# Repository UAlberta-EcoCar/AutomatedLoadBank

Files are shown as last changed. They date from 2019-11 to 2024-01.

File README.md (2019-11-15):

# AutomatedLoadBank
Python user interface for Raspberry Pi driven automated load bank

### Project Abstract
An automated resistive load bank was created to test and optimize hydrogen fuel cells for the University of Alberta EcoCar team. The load bank utilizes a touchscreen graphical user interface to select automated testing cycles and pulse width modulation for a variable load. The load bank handles up to 60 A of current from the 46 V fuel cell with 1000 W of power dissipation capability. Furthermore, it is battery powered, portable, and weather resistant.

### Software Overview
The automated load bank is managed primarily by a Raspberry Pi computer, and its I/O capabilities are extended using an Atmel ATMega328P. In this repository lies the software for the Raspberry Pi. The software is primarily written in Python and uses the TkInter graphics library to develop a touchscreen user interface.

### Communication With Other Modules
#### ATMega328P via I2C
*Raspberry Pi to ATMega328P*
* 0 -- Stop output
* 1-120 -- Desired load in steps. Step size is 0.5 A, so a value of 64 would correspond to a 32 A load.
* 121 -- Start an air starve cycle. Operating parameters are set in the ATMega328P.
* 122 -- Data request for all inputs read by ATMega328P. (Fuel cell voltage, fuel cell current, battery voltage)
* 123 -- Trigger to tell ATMega328P that fan speeds will be sent next.
* **WARNING:** Sending values greater than 123 will be interpreted by the ATMega328P as desired current values of greater than 60 A which is outside the design parameters for the hardware.

*ATMega328P to Raspberry Pi*

### Version History

### Pi Configurations Necessary to Run this Software
**Install Raspbian operating system using Etcher to put the latest image on an SD card**\
    [TUTORIAL](https://www.raspberrypi.org/documentation/installation/installing-images/)
    
**Set date for Wi-Fi access**\
  `sudo date -s "Dec 27 14:54"`
    
**Update software repositories & installed software**\
  [TUTORIAL](https://www.raspberrypi.org/documentation/raspbian/updating.md)\
  `sudo apt-get update`\
  `sudo apt-get dist-upgrade`

**Install "Matchbox" on-screen software keyboard**\
  `sudo apt-get install matchbox-keyboard`
    
**Install TkInter and Python image library**\
`sudo apt-get install tk`\
`sudo apt-get install python-imaging`\
`sudo apt-get install python-imaging-tk`\
`sudo apt-get install python3-pil.imagetk`

**Set Python3 as default environment**\
Edit bash file: `nano ~/.bashrc`\
Add at the end:
```
alias python='/usr/bin/python3'
alias pip=pip3
```
Run bash file: `source ~/.bashrc`

**Enable I2C**\
`sudo raspi-config` -> **5 Interfacing Options** -> **P5 I2C** -> **yes** -> **Finish**

**Set I2C Speed**\
[REFERENCE](https://www.raspberrypi-spy.co.uk/2018/02/change-raspberry-pi-i2c-bus-speed/)\
`sudo nano /boot/config.txt`\
`dtparam=i2c_arm=on,i2c_arm_baudrate=15000` (for 15kHz baud rate)

**Add Matplotlib dependencies**
```
sudo apt-get install libatlas3-base libffi-dev at-spi2-core python3-gi-cairo
pip install cairocffi
pip install matplotlib
```

### Handy Features/Resources
**Display brightness**\
`sudo bash -c "echo n > /sys/class/backlight/rpi_backlight/brightness"`\
where 0 < n < 255 (255 is maximum brightness)\
[*Alternate Method*](https://raspberrypi.stackexchange.com/questions/46225/adjusting-the-brightness-of-the-official-touchscreen-display)
```
>>> import rpi_backlight as bl
>>> bl.set_brightness(255)
>>> bl.set_brightness(20, smooth=True, duration=3)
>>> bl.get_max_brightness()
255
>>> bl.get_actual_brightness()
20
>>> bl.get_power()
True
>>> bl.set_power(False)
```

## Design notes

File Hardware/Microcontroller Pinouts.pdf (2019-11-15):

## Raspberry Pi

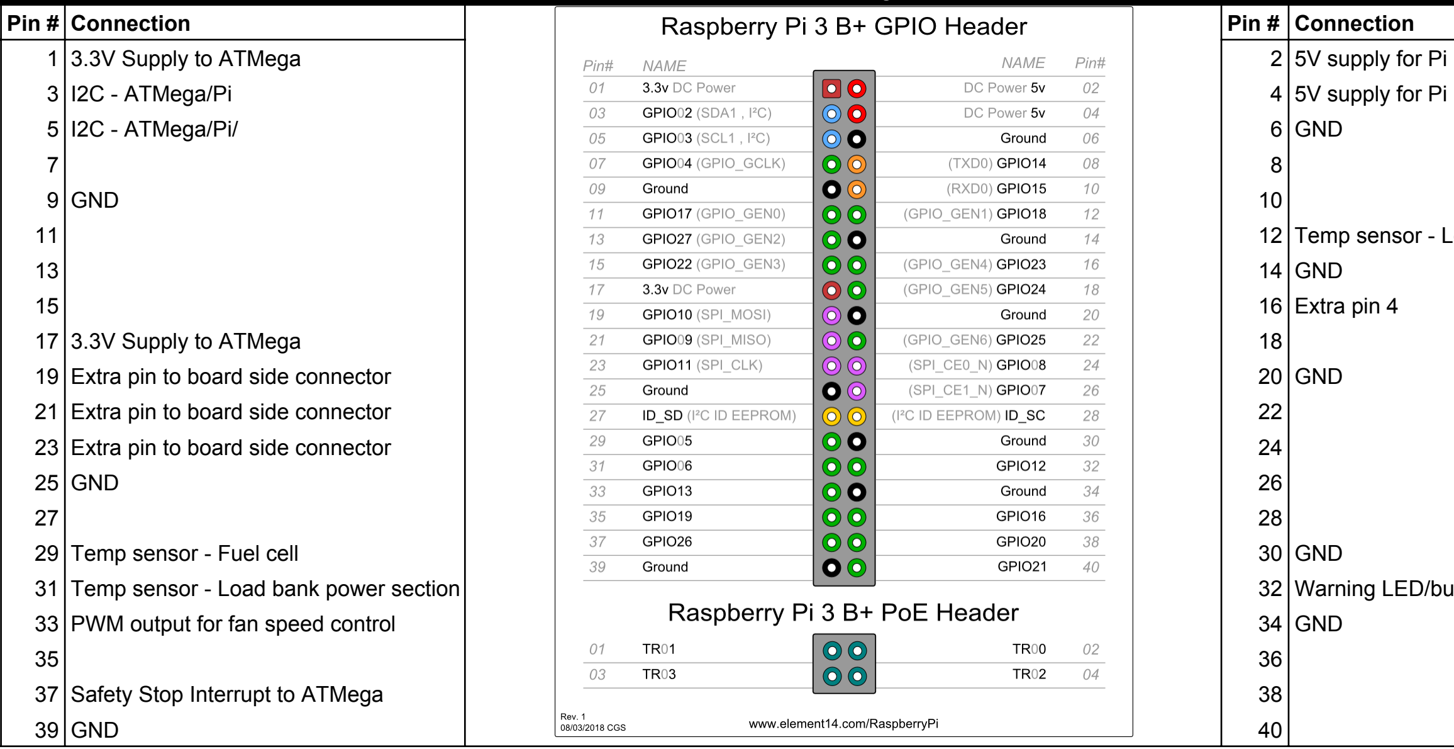
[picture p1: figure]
Pin #; Connection; 3.3V Supply to ATMega; 5V supply for Pi; I2C - ATMega/Pi; I2C - ATMega/Pi/; GND; Extra pin 4; Extra pin to board side connector; Temp sensor - Fuel cell; Safety Stop Interrupt to ATMega

11 | 12 | Temp sensor - Load bank electronics
19 | Extra pin to board side connector | 20 | GND
31 | Temp sensor - Load bank power section | 32 | Warning LED/buzzer output
33 | PWM output for fan speed control | 34 | GND

## Atmel ATMega 328P

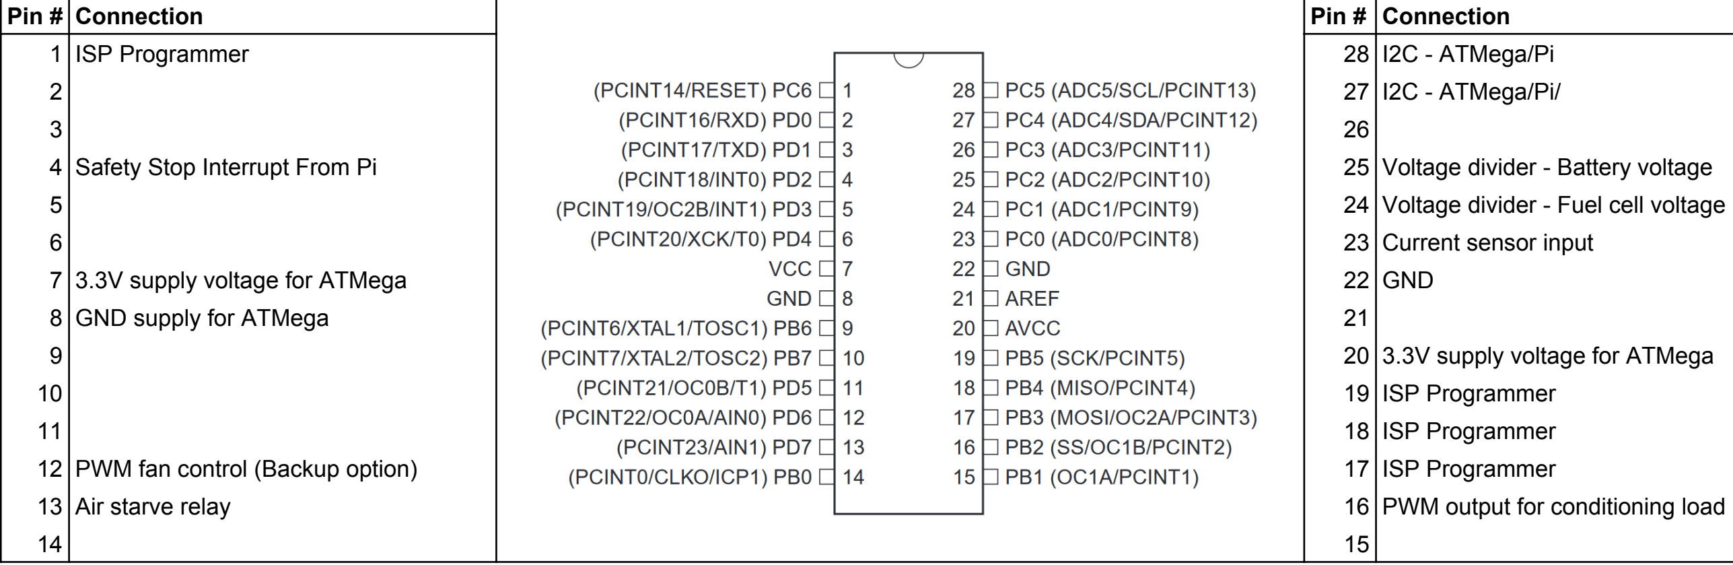
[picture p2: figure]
Pin #; Connection; ISP Programmer; I2C - ATMega/Pi; I2C - ATMega/Pi/; Safety Stop Interrupt From Pi; Voltage divider - Battery voltage; Current sensor input; 3.3V supply voltage for ATMega; GND; GND supply for ATMega; PWM fan control (Backup option); Air starve relay; PWM output for conditioning load

5 | 24 | Voltage divider - Fuel cell voltage

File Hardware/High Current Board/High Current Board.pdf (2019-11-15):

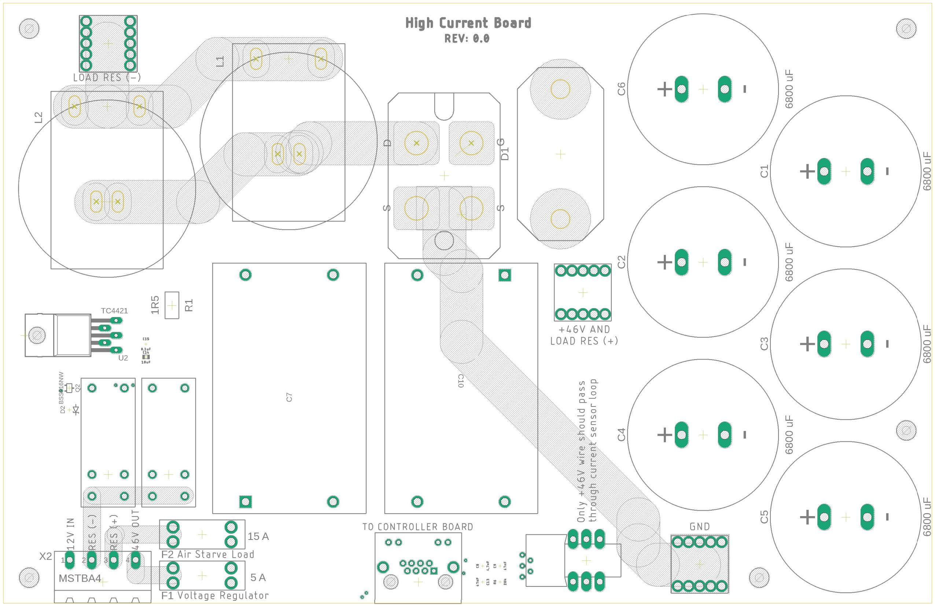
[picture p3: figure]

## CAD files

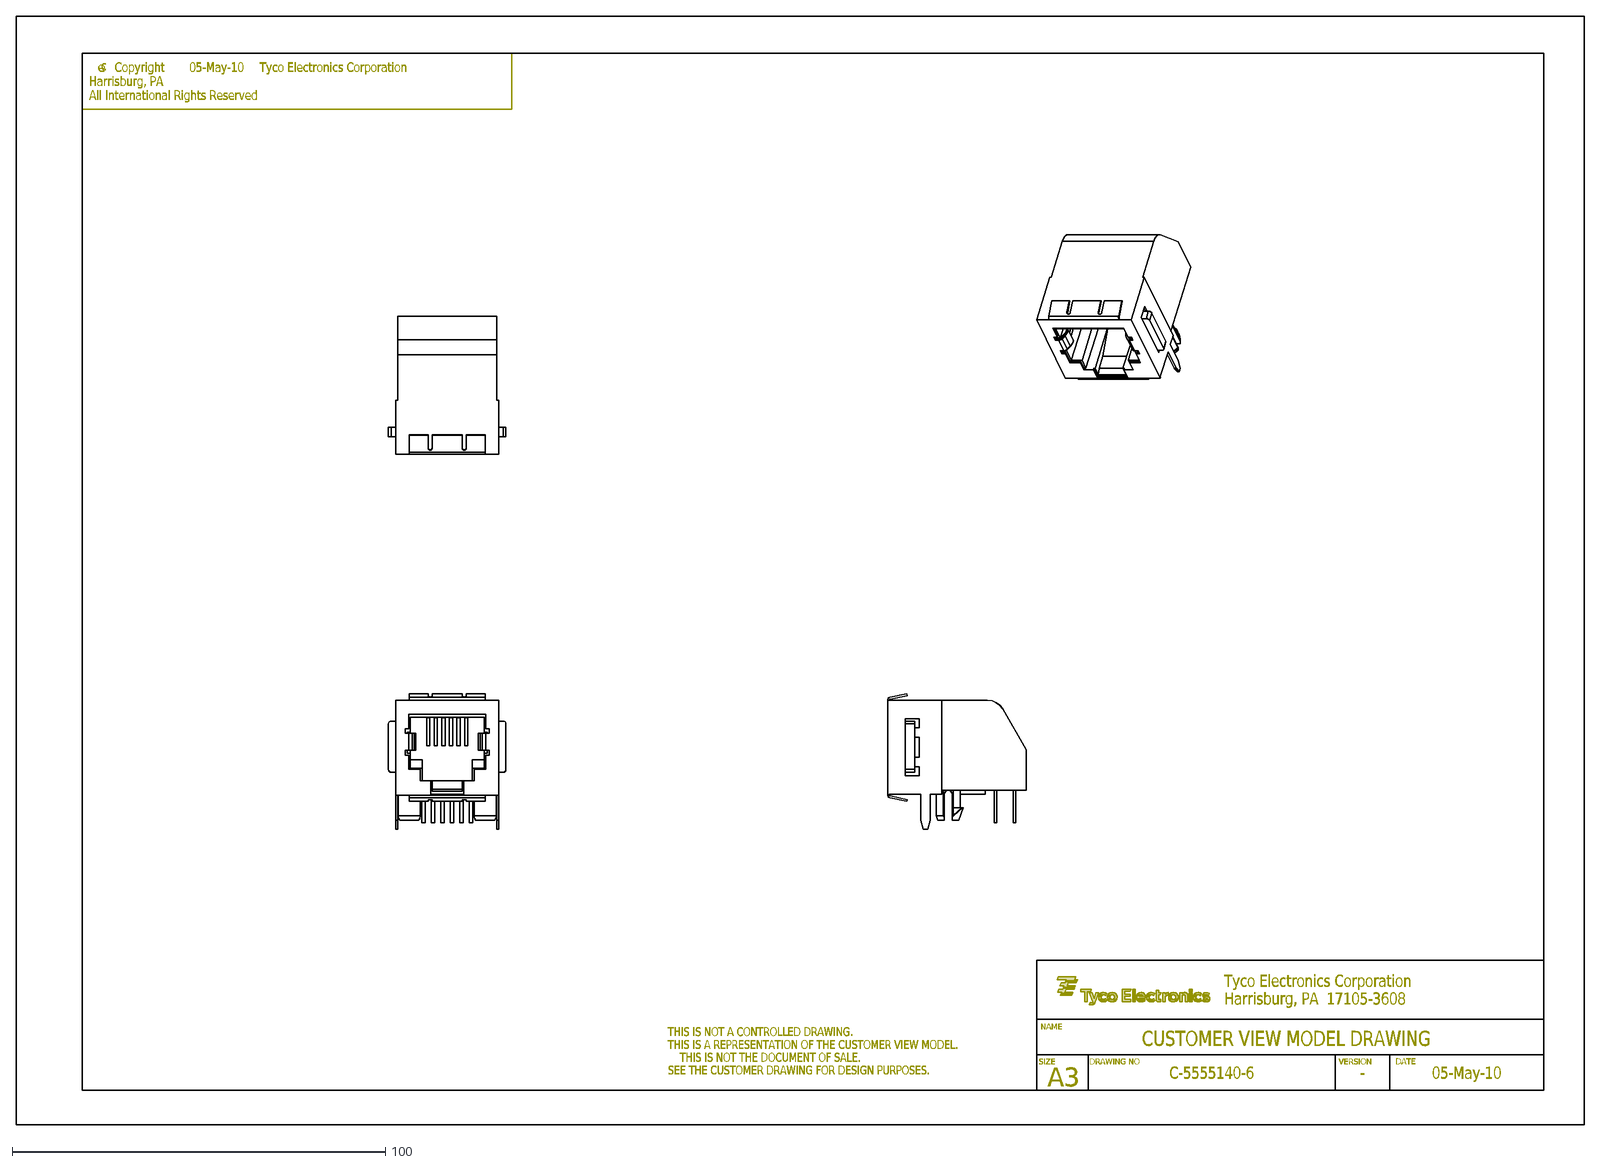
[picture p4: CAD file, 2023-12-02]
references/c-5555140-6-e-2d.dxf
SIZE
DRAWING NO
VERSION
NAME
A3
CUSTOMER VIEW MODEL DRAWING
Tyco Electronics Corporation
Harrisburg, PA 17105-3608
DATE
THIS IS NOT A CONTROLLED DRAWING.
THIS IS A REPRESENTATION OF THE CUSTOMER VIEW MODEL.
THIS IS NOT THE DOCUMENT OF SALE.
SEE THE CUSTOMER DRAWING FOR DESIGN PURPOSES.
c
C-5555140-6
-
05-May-10
Copyright
Harrisburg, PA
All International Rights Reserved

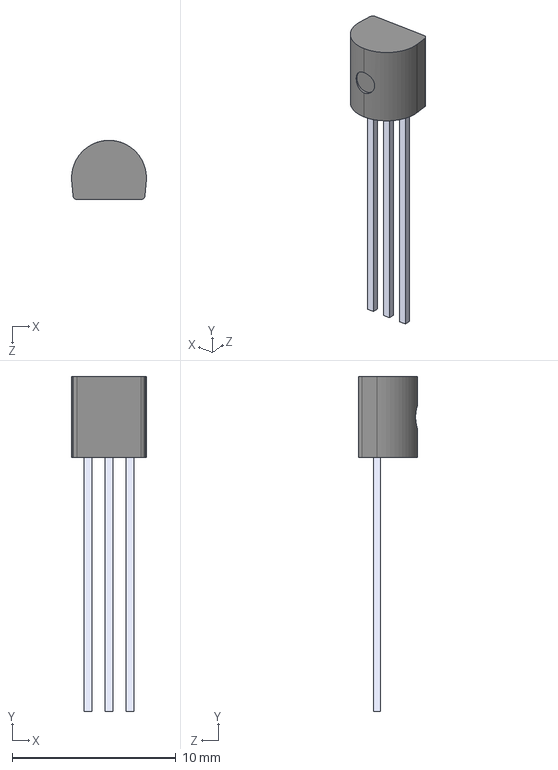
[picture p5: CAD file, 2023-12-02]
references/DS18B20/DS18B20.step
4.57 x 20.4 x 3.62 mm

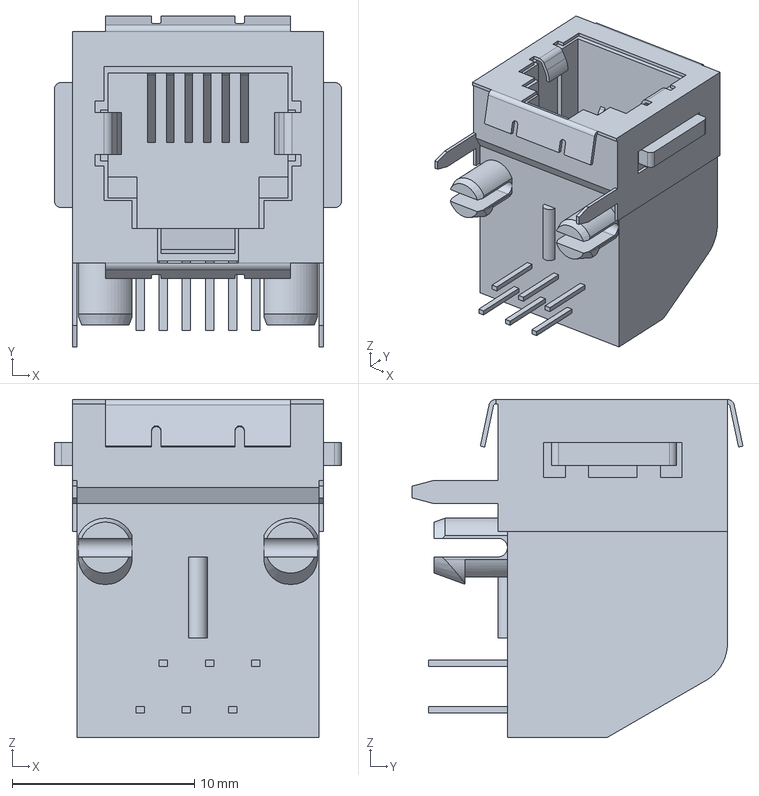
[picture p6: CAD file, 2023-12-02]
references/c-5555140-6-e-3d.stp
15.7 x 18.1 x 18.5 mm

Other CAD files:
references/c-5555140-6-e-3d.igs

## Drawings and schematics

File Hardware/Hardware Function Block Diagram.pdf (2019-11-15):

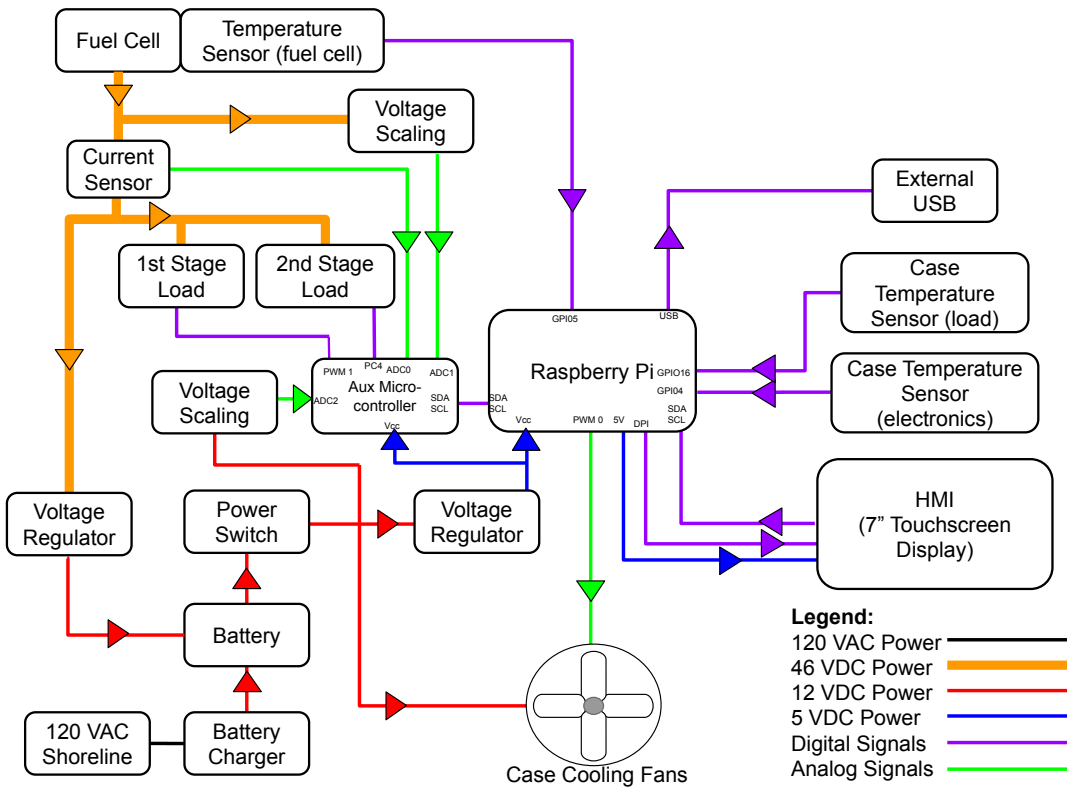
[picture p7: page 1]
Legend: 120 VAC Power 46 VDC Power 12 VDC Power 5 VDC Power Digital Signals Analog Signals; Fuel Cell; 120 VAC Shoreline; Raspberry Pi; HMI (7” Touchscreen Display); Case Temperature Sensor (load); Case Temperature Sensor (electronics); External USB; Battery; Voltage Regulator; Power Switch; Voltage Scaling; Battery Charger; 1st Stage Load; 2nd Stage Load; Current Sensor; Aux Micro- controller ADC2; PWM 1; ADC0; ADC1; SDA SCL; SDA SCL Vcc Vcc; GPI05; GPI04; GPIO16; USB; PWM 0; DPI; SDA; SCL

Temperature
Sensor (fuel cell)

Case Cooling Fans

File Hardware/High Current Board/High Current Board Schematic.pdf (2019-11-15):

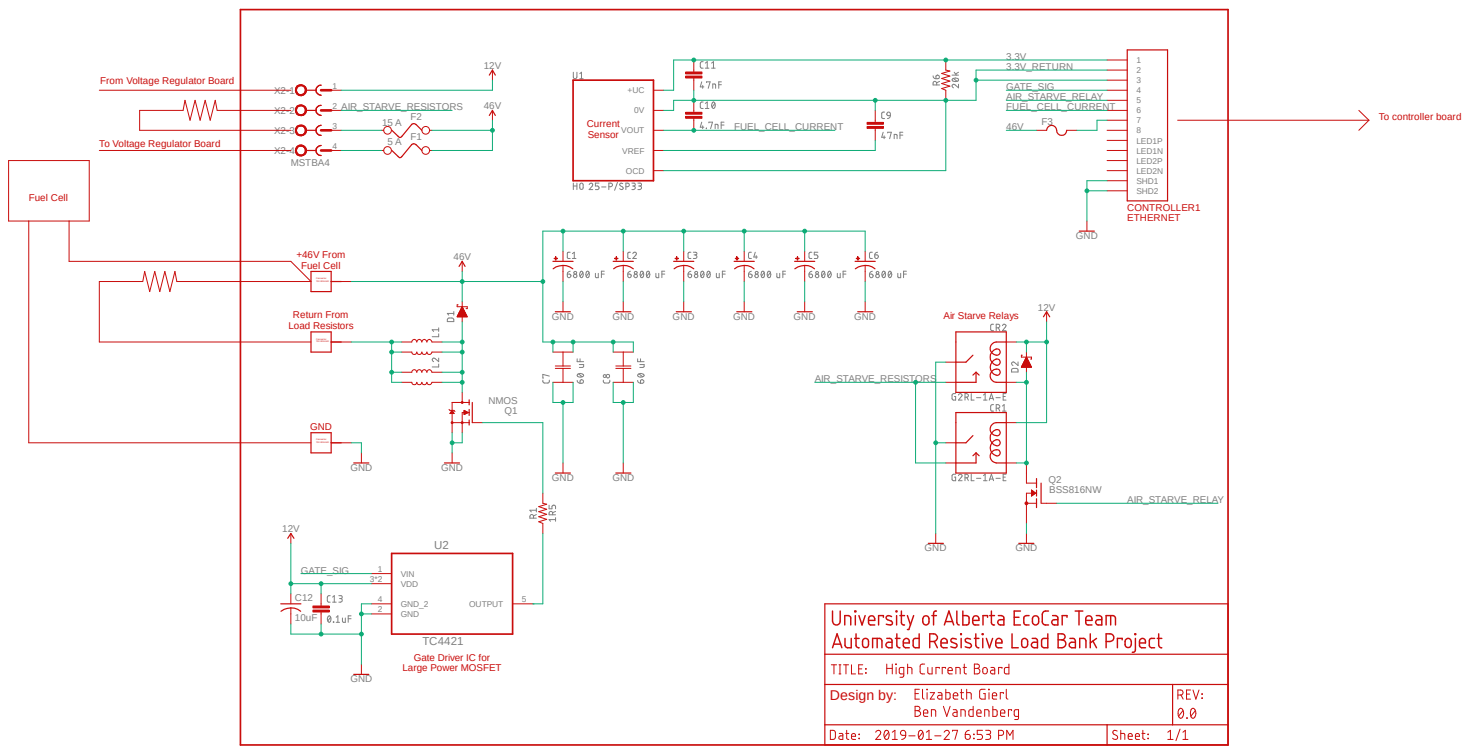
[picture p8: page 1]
GND; 46V GND; NMOS GND; BSS816NW; MSTBA4; GND GND; 1 2 3 4 5 6 7 8 LED1P LED1N LED2P LED2N SHD1 SHD2 Q2; GND 2; GND_2 4; OUTPUT; 5 VDD 3*2; VIN 1; F3 FUEL_CELL_CURRENT; FUEL_CELL_CURRENT; 3.3V 3.3V_RETURN; AIR_STARVE_RELAY; GATE_SIG; AIR_STARVE_RESISTORS; Current Sensor +46V From; Fuel Cell; To controller board To Voltage Regulator Board; From Voltage Regulator Board; Connector 732-3204-ND Connector 732-3204-ND; Design by:; Connector 732-3204-ND; CONTROLLER1 ETHERNET

VOUT VREF OCD Q1

Fuel Cell Return From

Air Starve Relays Gate Driver IC for Large Power MOSFET

Load Resistors GND

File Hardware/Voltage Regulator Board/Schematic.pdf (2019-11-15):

## INGND

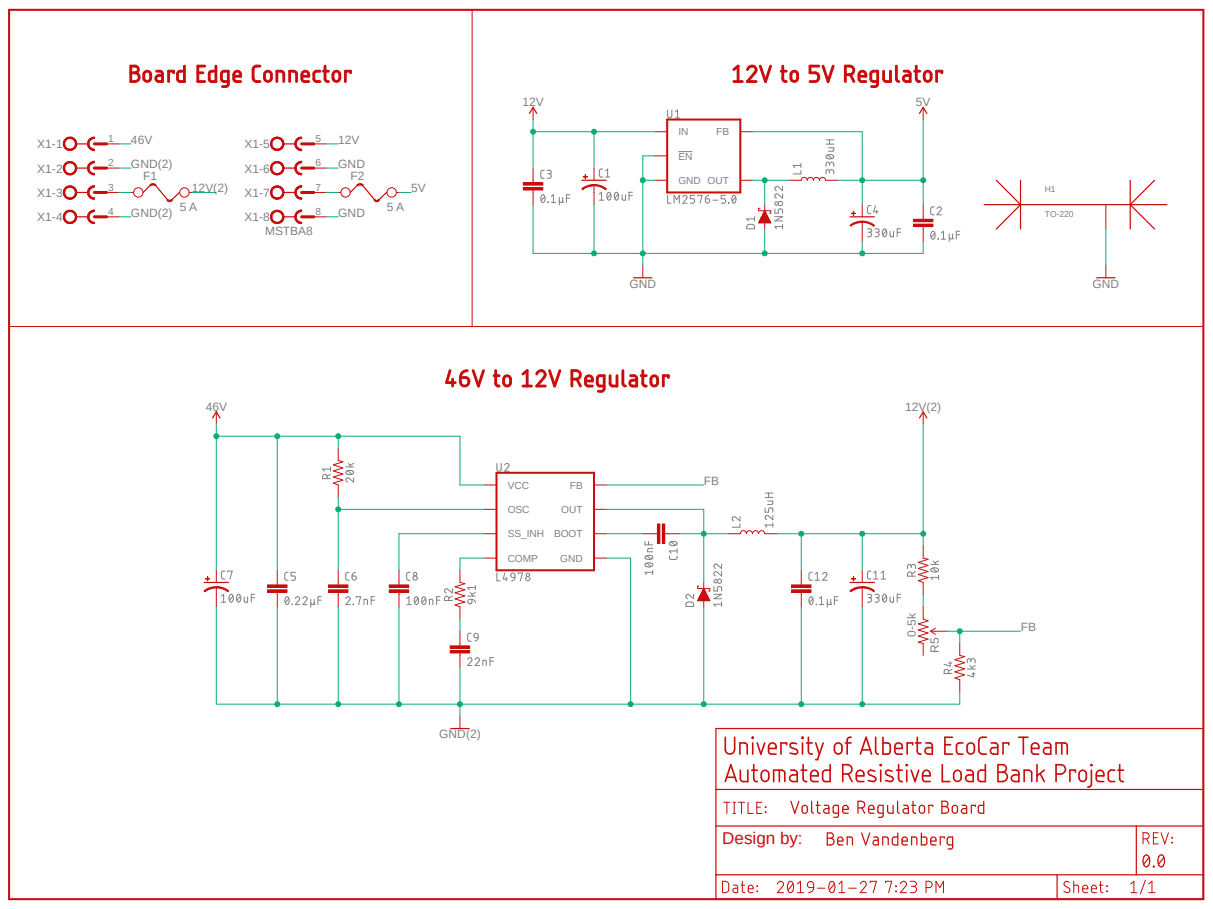
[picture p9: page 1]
GND; GND(2); MSTBA8; OUT; VCC; SS_INH; FB OSC; BOOT OUT COMP; Design by:

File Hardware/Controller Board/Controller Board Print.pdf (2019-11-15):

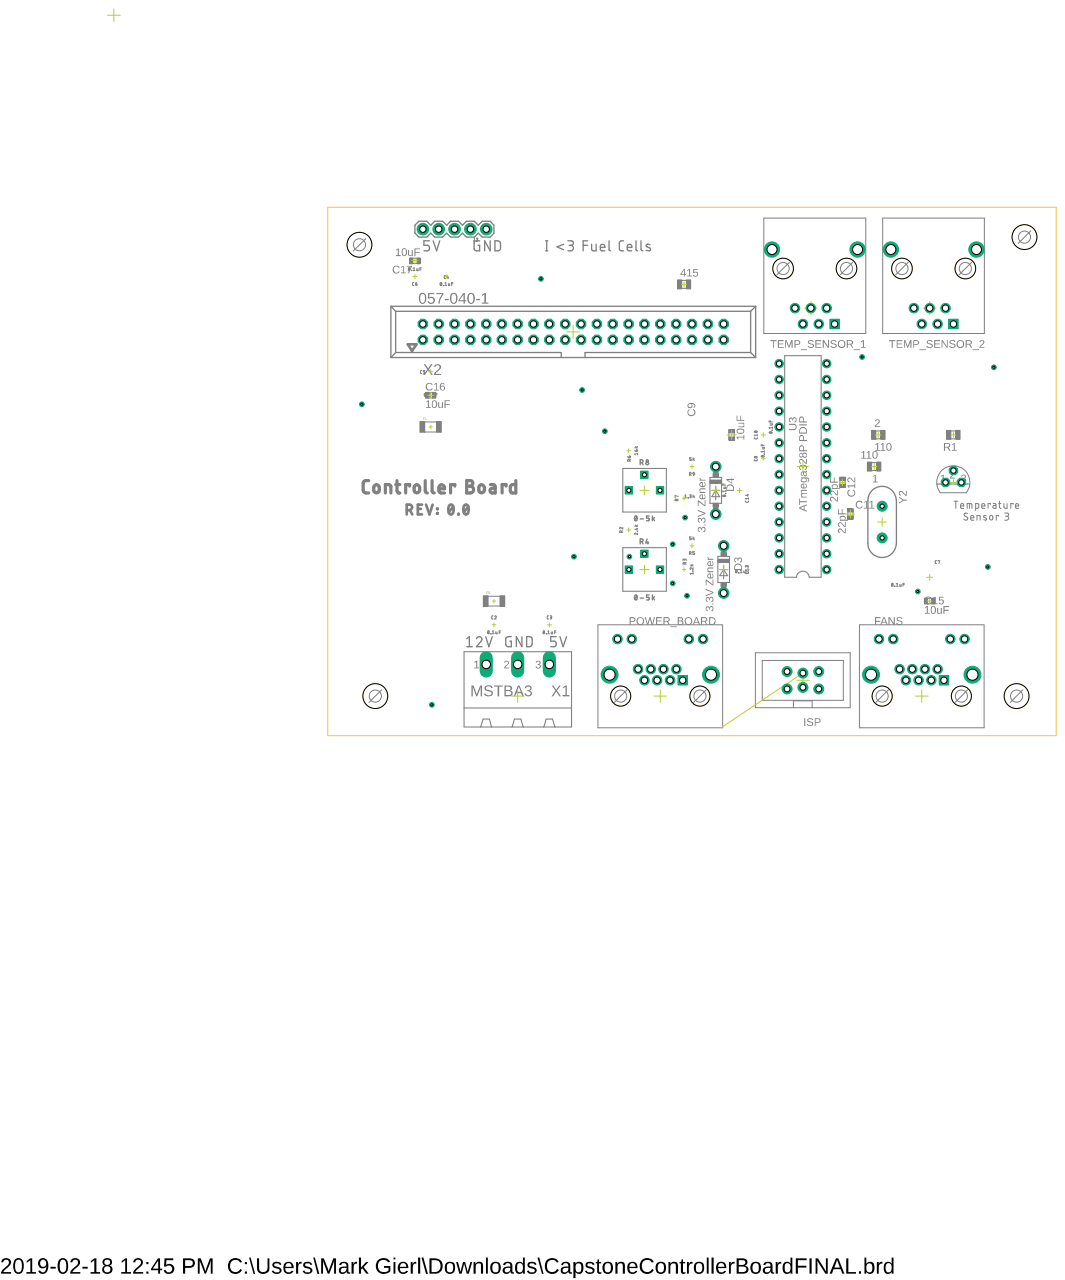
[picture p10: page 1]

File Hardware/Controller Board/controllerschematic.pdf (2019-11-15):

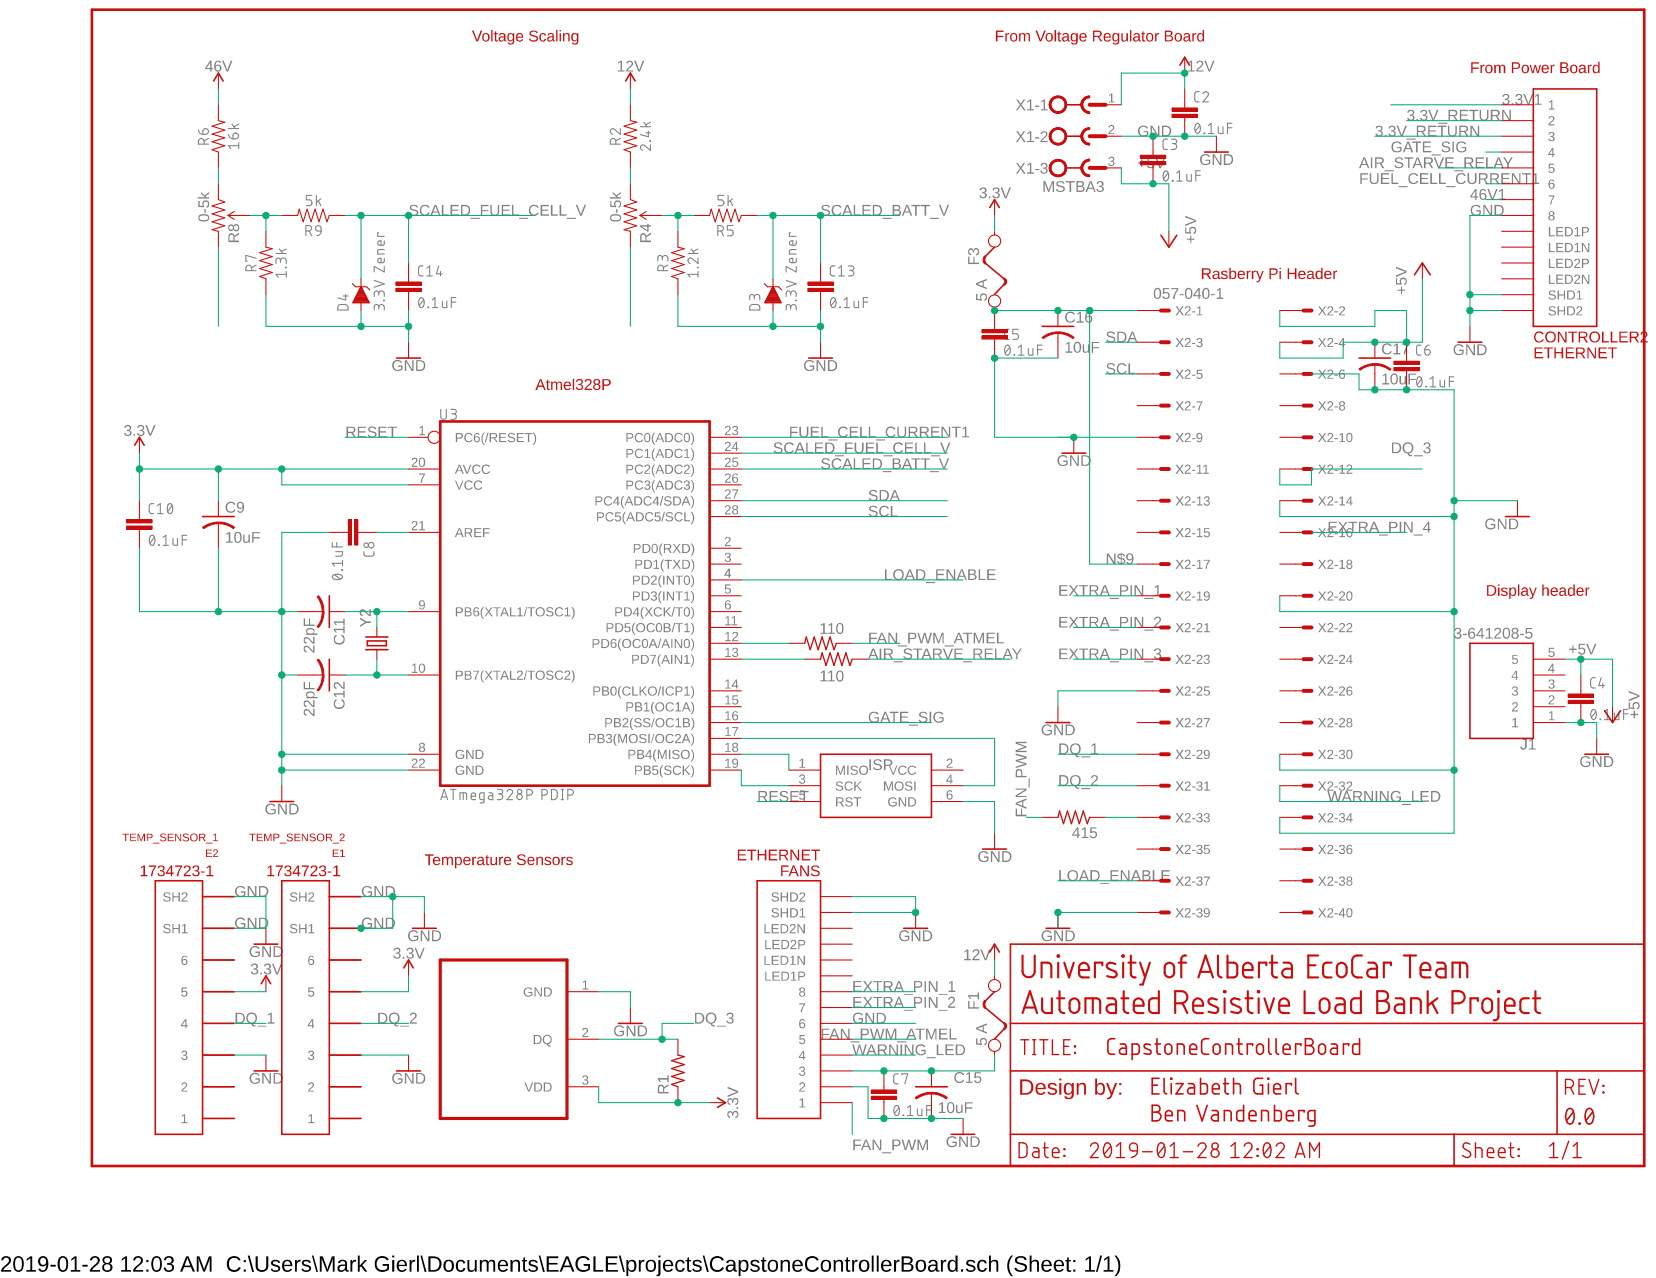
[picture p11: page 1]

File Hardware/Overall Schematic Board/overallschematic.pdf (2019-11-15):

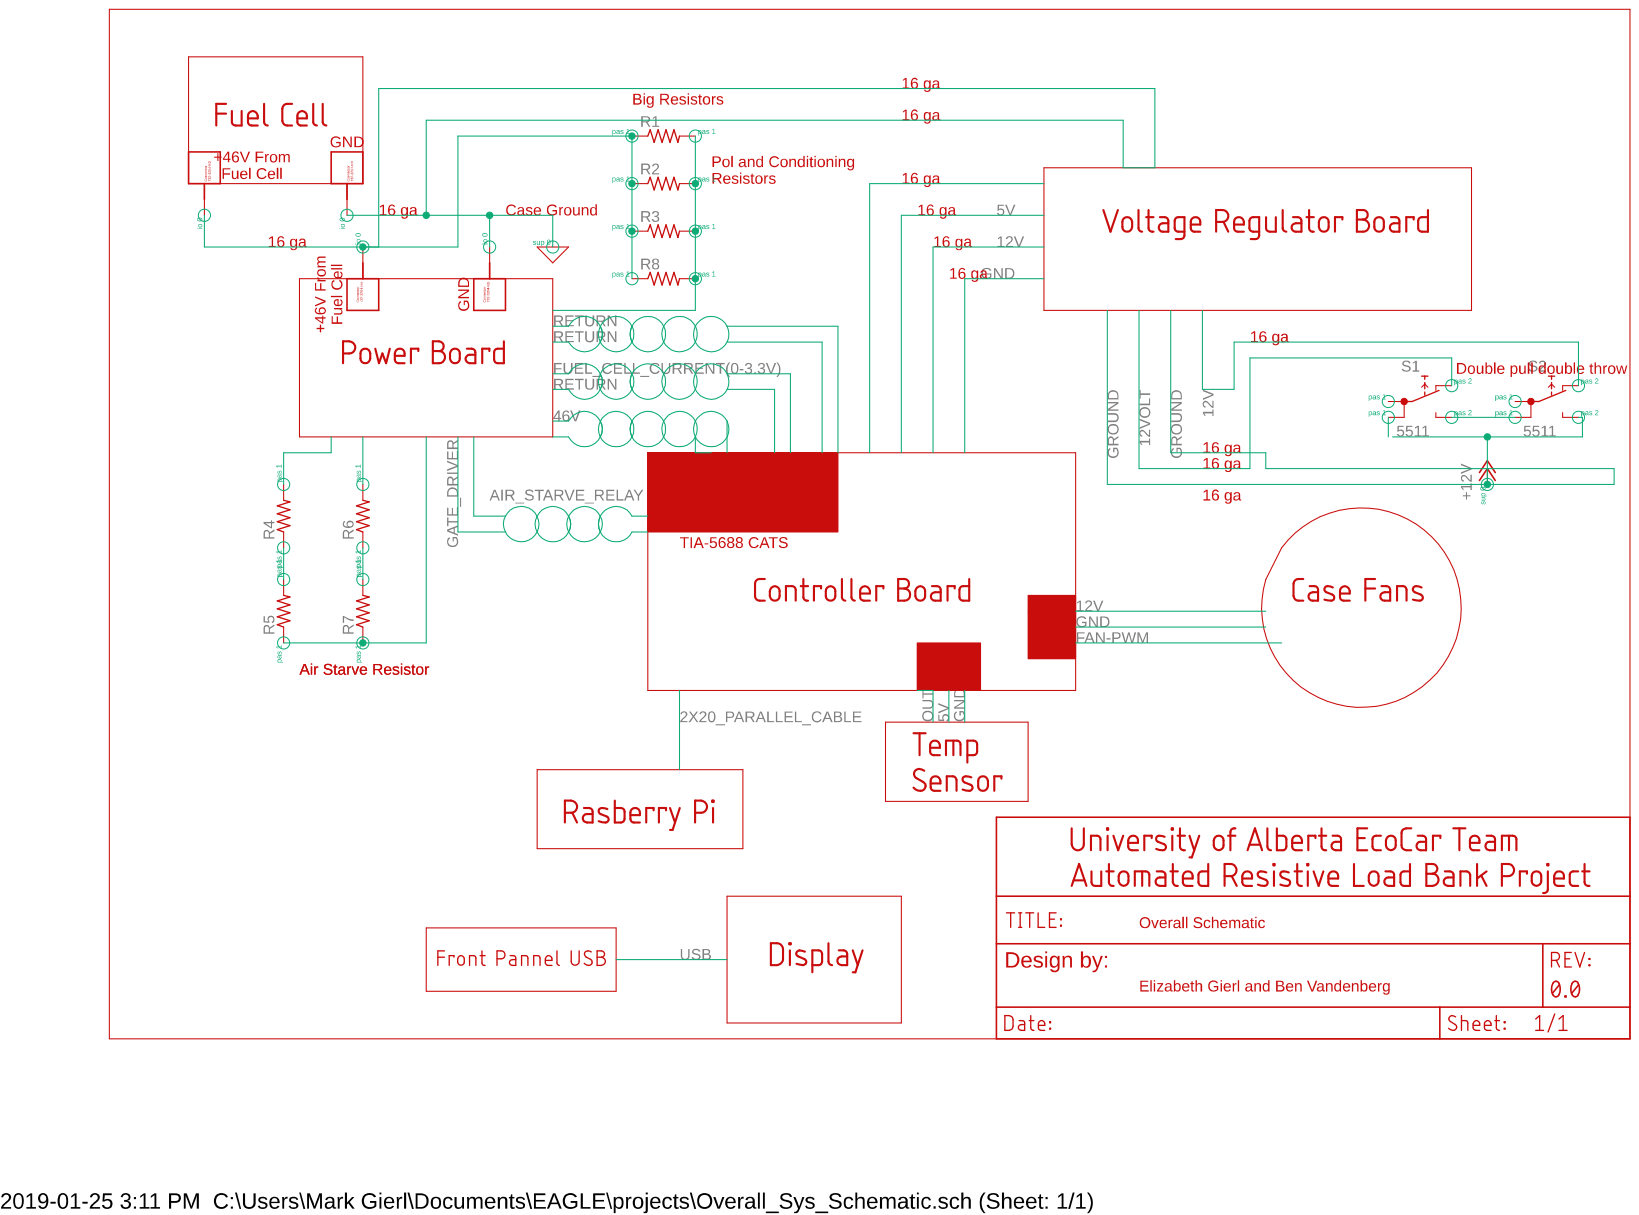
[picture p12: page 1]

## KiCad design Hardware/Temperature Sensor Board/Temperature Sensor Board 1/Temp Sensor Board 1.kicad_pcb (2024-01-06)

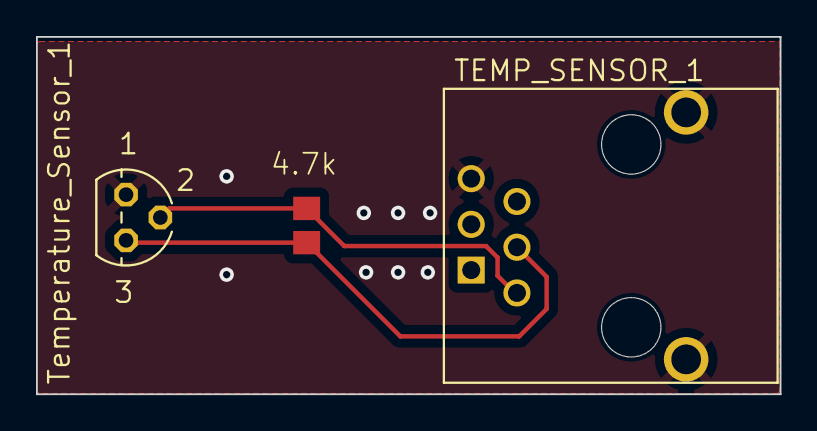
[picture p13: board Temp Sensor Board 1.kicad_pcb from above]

Board: 2 copper layers, 41.3 x 19.9 mm, 3 parts (0 on the bottom side), 3 nets.

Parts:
4.7k: R; R0805
J1: 6P6C; 1734723-1_RJ11
U$1: Temperature_Sensor_1; TO92-3

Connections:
/DQ: 4.7k.1, J1.4, U$1.2 (DQ)
/GND: J1.3, J1.SH1, J1.SH2, U$1.1 (GND)
/VDD: 4.7k.2, J1.5, U$1.3 (VDD)

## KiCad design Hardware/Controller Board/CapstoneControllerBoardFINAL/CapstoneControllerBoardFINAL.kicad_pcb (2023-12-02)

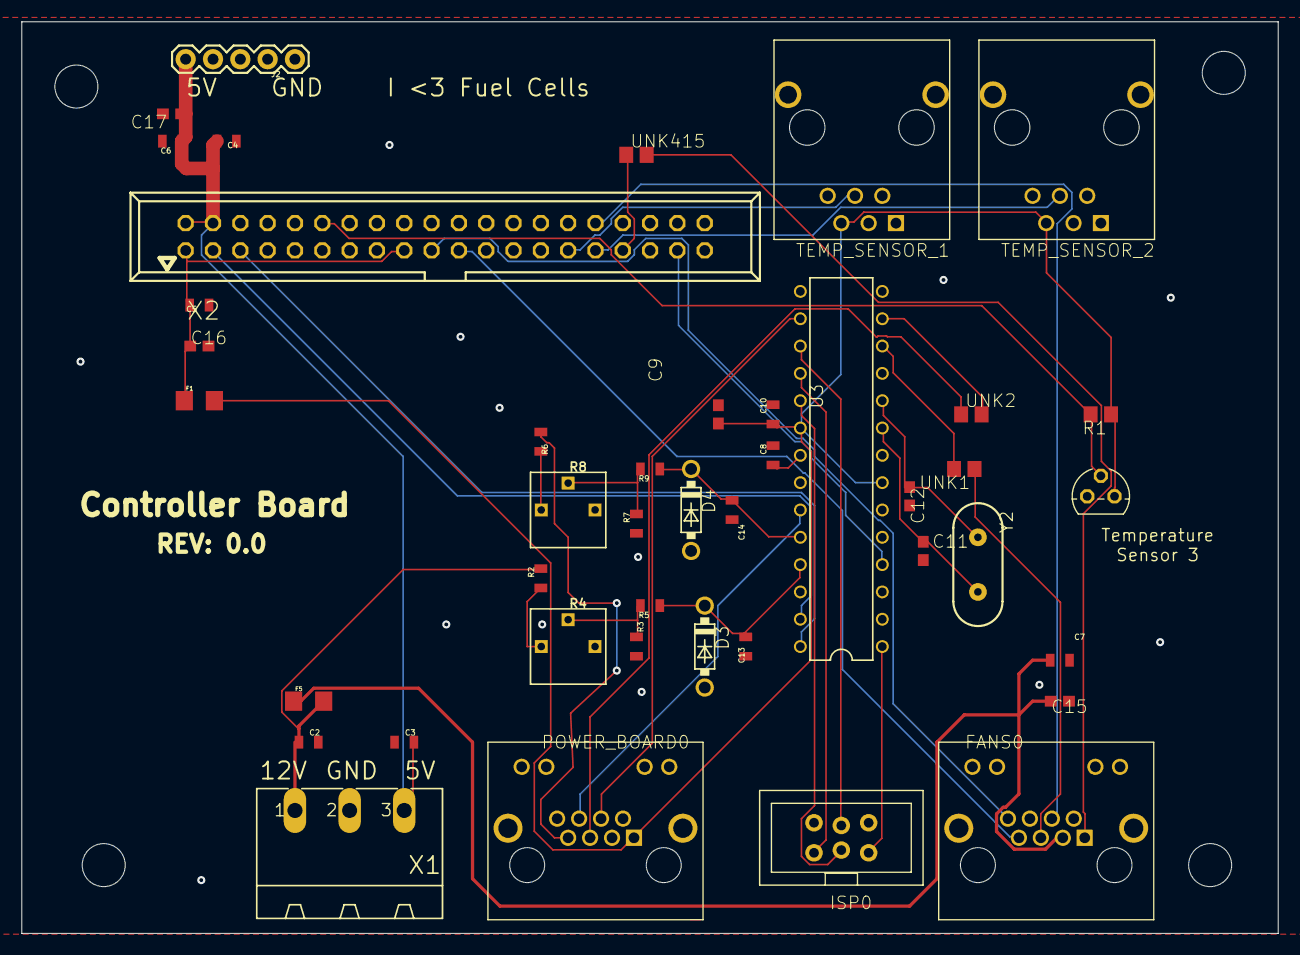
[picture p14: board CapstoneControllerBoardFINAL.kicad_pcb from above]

Board: 2 copper layers, 116.8 x 84.8 mm, 48 parts (0 on the bottom side), 37 nets.

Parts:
@HOLE0, @HOLE1, @HOLE2, @HOLE3: (no value)
C2, C3, C4, C5, C6, C7, C8, C10, C13, C14: 0.1uF; 0805
C9, C15, C16, C17: 10uF; C0603
C11, C12: 22pF; C0603
D3, D4: 3.3V Zener; DO41-7.6
F1, F5: 1206
FANS0: ETHERNET; A122645-ND
FRAME2: FRAME-LETTERNO_PACKAGE; DUMMY
ISP0: AVRISP-BOX
J2: 1X05
POWER_BOARD0: ETHERNET; A122645-ND
R1: R0805
R2: 2.4k; 0805
R3: 1.2k; 0805
R4, R8: 0-5k; TRIM_POT
R5, R9: 5k; 0805
R6: 16k; 0805
R7: 1.3k; 0805
TEMP_SENSOR_1, TEMP_SENSOR_2: 5555140-6; 1734723-1_RJ11
U3: ATmega328P PDIP; PDIP-T28
U$2: DS18B; TO92
UNK1, UNK2: 110; R0805
UNK415: R0805
X1: MSTBA3
X2: 057-040-1
Y2: HC49US

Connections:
3.3V: C9.1, C10.1, F1.2, POWER_BOARD0.P$1, R1.1, TEMP_SENSOR_1.5, TEMP_SENSOR_2.5, U3.7, U3.20, U$2.3
12V: C2.1, F5.2, R2.2, X1.1
46V: POWER_BOARD0.P$7, R6.2
+5V: C3.2, C4.1, C6.1, C17.1, J2.5, X1.3, X2.2, X2.4
AIR_STARVE_RELAY: POWER_BOARD0.P$5, UNK2.1
DQ_1: TEMP_SENSOR_1.4, X2.29
DQ_2: TEMP_SENSOR_2.4, X2.31
DQ_3: R1.2, U$2.2, X2.12
EXTRA_PIN_1: FANS0.P$8, X2.19
EXTRA_PIN_2: FANS0.P$7, X2.21
FAN_PWM: FANS0.P$1, UNK415.2
FAN_PWM_ATMEL: FANS0.P$5, UNK1.1
FUEL_CELL_CURRENT1: POWER_BOARD0.P$6, U3.23
GATE_SIG: POWER_BOARD0.P$4, U3.16
GND: C2.2, C3.1, C4.2, C5.2, C6.2, C7.2, C8.2, C9.2, C10.2, C11.2, C12.2, C13.2, C14.2, C15.2, C16.2, C17.2, D3.A, D4.A, FANS0.P$2, FANS0.P$6, FANS0.P$13, FANS0.P$14, ISP0.6, J2.1, POWER_BOARD0.P$2, POWER_BOARD0.P$3, POWER_BOARD0.P$8, POWER_BOARD0.P$13, POWER_BOARD0.P$14, R3.1, R7.1, TEMP_SENSOR_1.3, TEMP_SENSOR_1.SH1, TEMP_SENSOR_1.SH2, TEMP_SENSOR_2.3, TEMP_SENSOR_2.SH1, TEMP_SENSOR_2.SH2, U3.8, U3.22, U$2.1, X1.2, X2.9, X2.14, X2.20, X2.25, X2.30, X2.39
LOAD_ENABLE: U3.4, X2.37
unnamed: C8.1, U3.21
unnamed: ISP0.1, U3.18
unnamed: ISP0.3, U3.19
unnamed: UNK415.1, X2.33
unnamed: R2.1, R4.1
unnamed: U3.12, UNK1.2
unnamed: C5.1, C16.1, F1.1, X2.1, X2.17
unnamed: R6.1, R8.1
unnamed: R3.2, R4.2, R5.2
unnamed: ISP0.4, U3.17
unnamed: C11.1, U3.9, Y2.2
unnamed: C12.1, U3.10, Y2.1
unnamed: R7.2, R8.2, R9.2
unnamed: C7.1, C15.1, F5.1, FANS0.P$3
unnamed: U3.13, UNK2.2
RESET: ISP0.5, U3.1
SCALED_BATT_V: C13.1, D3.C, R5.1, U3.25
SCALED_FUEL_CELL_V: C14.1, D4.C, R9.1, U3.24
SCL: U3.28, X2.5
SDA: U3.27, X2.3
WARNING_LED: FANS0.P$4, X2.32

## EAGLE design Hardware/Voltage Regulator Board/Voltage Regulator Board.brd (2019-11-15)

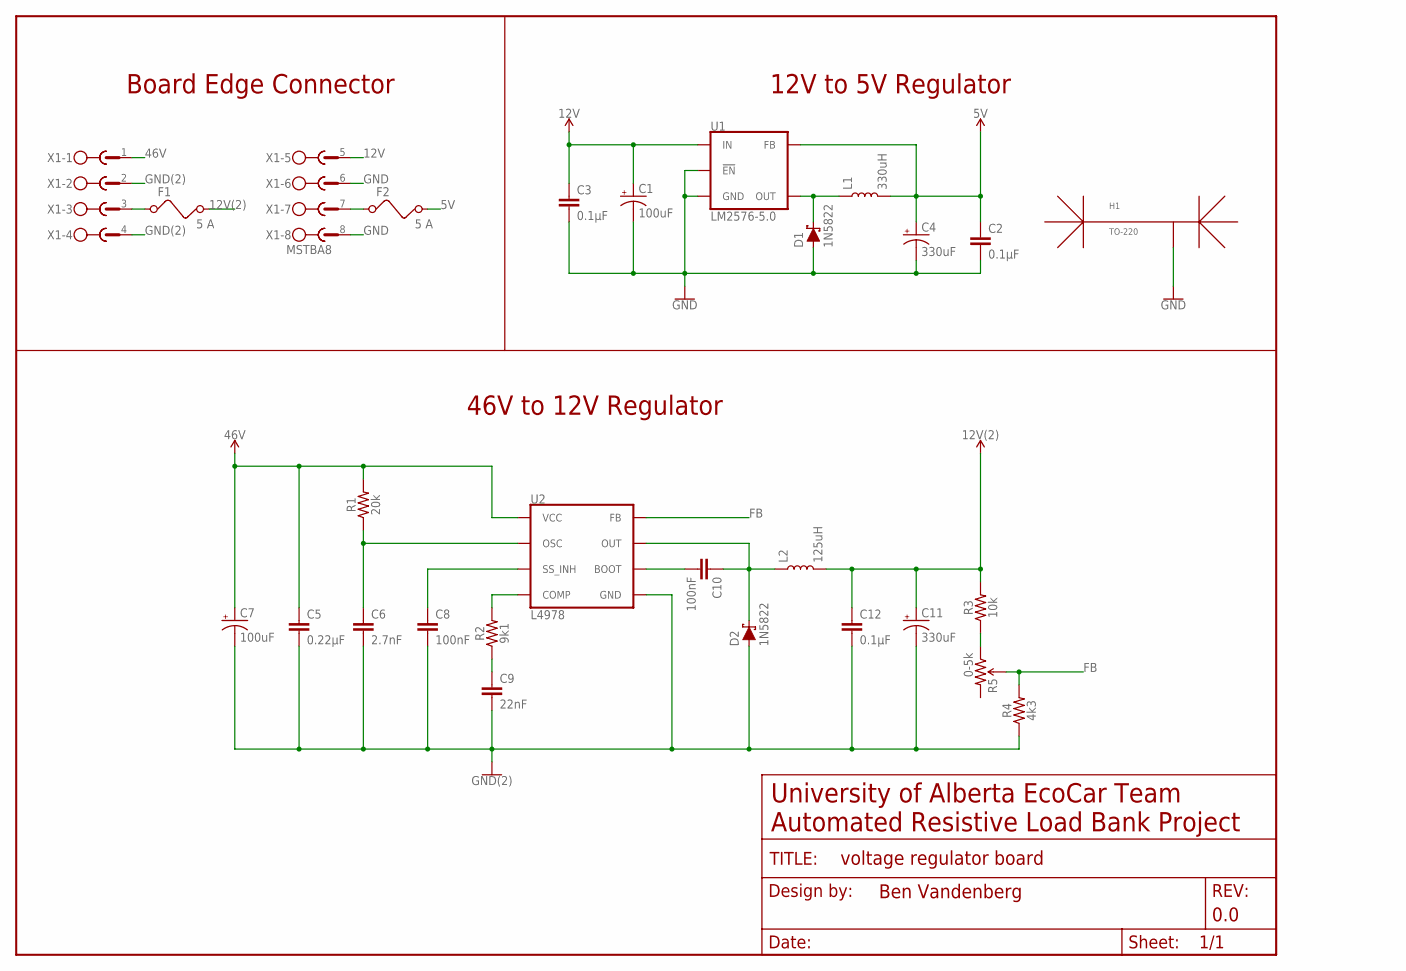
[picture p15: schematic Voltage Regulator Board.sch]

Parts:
C1, C7: 100uF; CPOL-RADIAL-3.5MM-8MM
C2, C3, C12: 0.1µF; 0805
C4, C11: 330uF; CPOL-RADIAL-5MM-10MM
C5: 0.22µF; 0805
C6: 2.7nF; 0805
C8, C10: 100nF; 0805
C9: 22nF; 0805
D1, D2: 1N5822; DO201T15
F1, F2: 5 A; KEYSTONE_ATM_FUSEHOLDER
FRAME1: FRAME-LETTERNO_PACKAGE; DUMMY
H1: TO-220; HSE-B250-04H_HEATSINK
L1: 330uH; 330UH_PTH_INDUCTOR
L2: 125uH; 125UH_PTH_INDUCTOR
R1: 20k; 0805
R2: 9k1; 0805
R3: 10k; 0805
R4: 4k3; 0805
R5: 0-5k; TRIM_POT
U1: LM2576-5.0; TO220-5
U2: L4978; DIP08
X1: MSTBA8

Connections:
5V: C2.1, C4.+, F2.R1 (2), F2.R2 (2), L1.P$2 (2), U1.4 (FB)
12V: C1.+, C3.1, U1.1 (IN), X1.5
12V(2): C11.+, C12.1, F1.R1 (2), F1.R2 (2), L2.P$2 (2), R3.2
46V: C5.1, C7.+, R1.2, U2.5 (VCC), X1.1
FB: R4.2, R5.2 (WIPER), U2.8 (FB)
GND: C1.-, C2.2, C3.2, C4.-, D1.A, H1.GND@1, H1.GND@2, U1.3 (GND), U1.5 (!EN), X1.6, X1.8
GND(2): C5.2, C6.2, C7.-, C8.2, C9.2, C11.-, C12.2, D2.A, R4.1, U2.1 (GND), X1.2, X1.4
unnamed: F1.L1 (1), F1.L2 (1), X1.3
unnamed: C6.1, R1.1, U2.3 (OSC)
unnamed: C8.1, U2.2 (SS_INH)
unnamed: R2.2, U2.7 (COMP)
unnamed: C9.1, R2.1
unnamed: F2.L1 (1), F2.L2 (1), X1.7
unnamed: C10.2, U2.6 (BOOT)
unnamed: C10.1, D2.C, L2.P$1 (1), U2.4 (OUT)
unnamed: R3.1, R5.1 (CCW)
OUT: D1.C, L1.P$1 (1), U1.2 (OUT)

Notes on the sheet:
University of Alberta EcoCar Team Automated Resistive Load Bank Project
12V to 5V Regulator
46V to 12V Regulator
Board Edge Connector

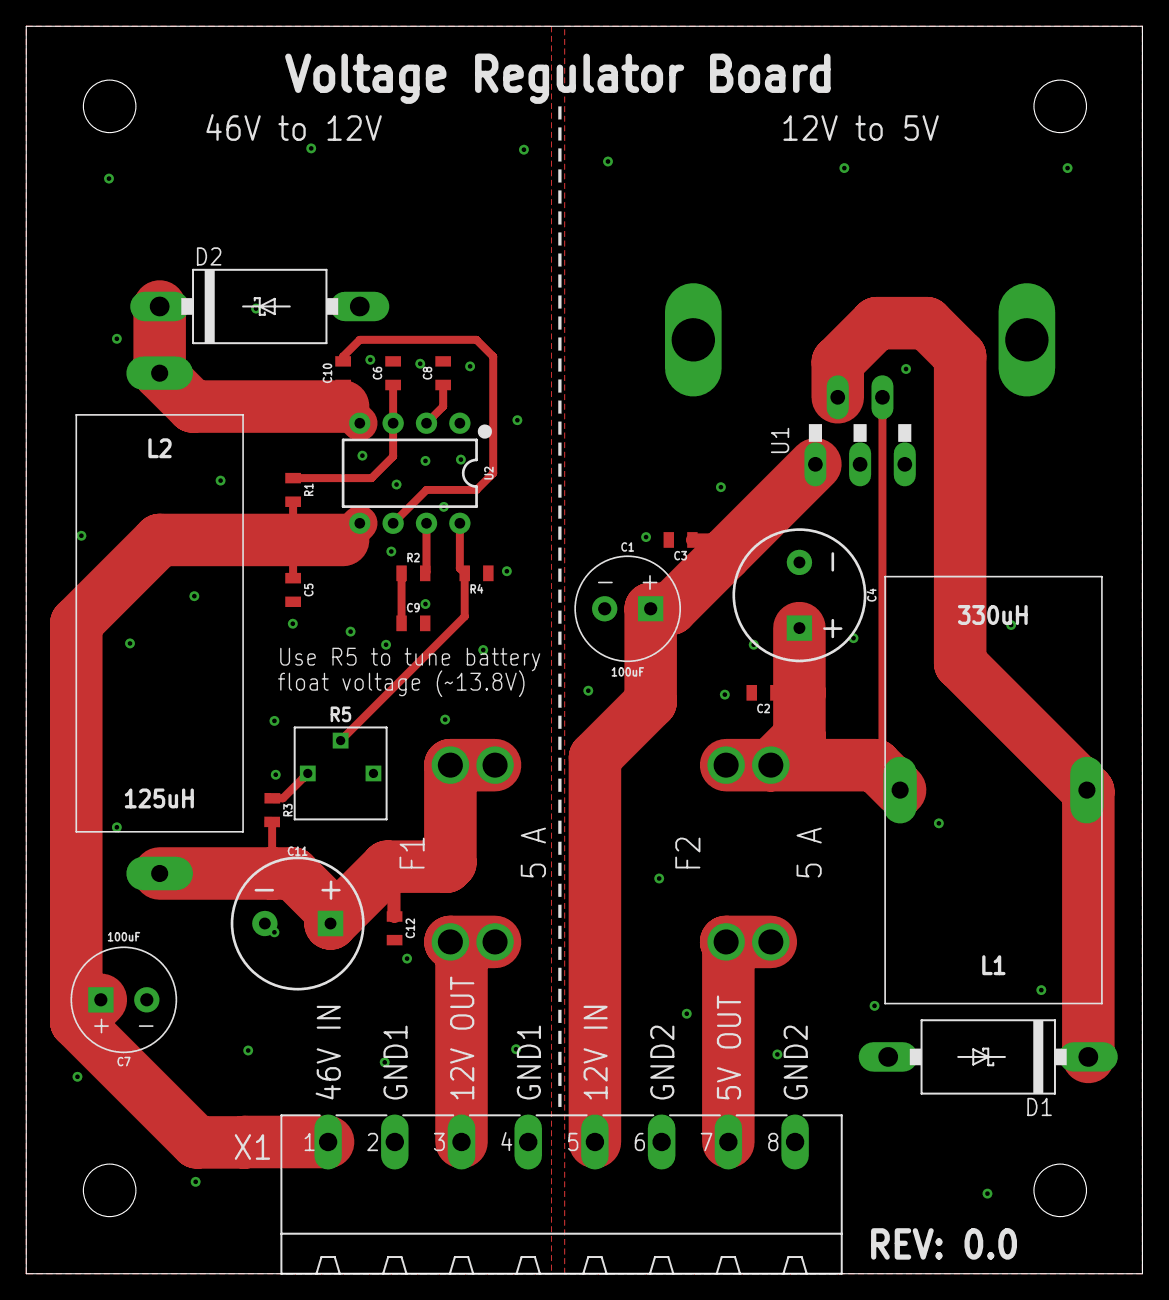
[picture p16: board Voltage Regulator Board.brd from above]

Board: 2 copper layers, 85.0 x 95.0 mm, 28 parts (0 on the bottom side), 17 nets.

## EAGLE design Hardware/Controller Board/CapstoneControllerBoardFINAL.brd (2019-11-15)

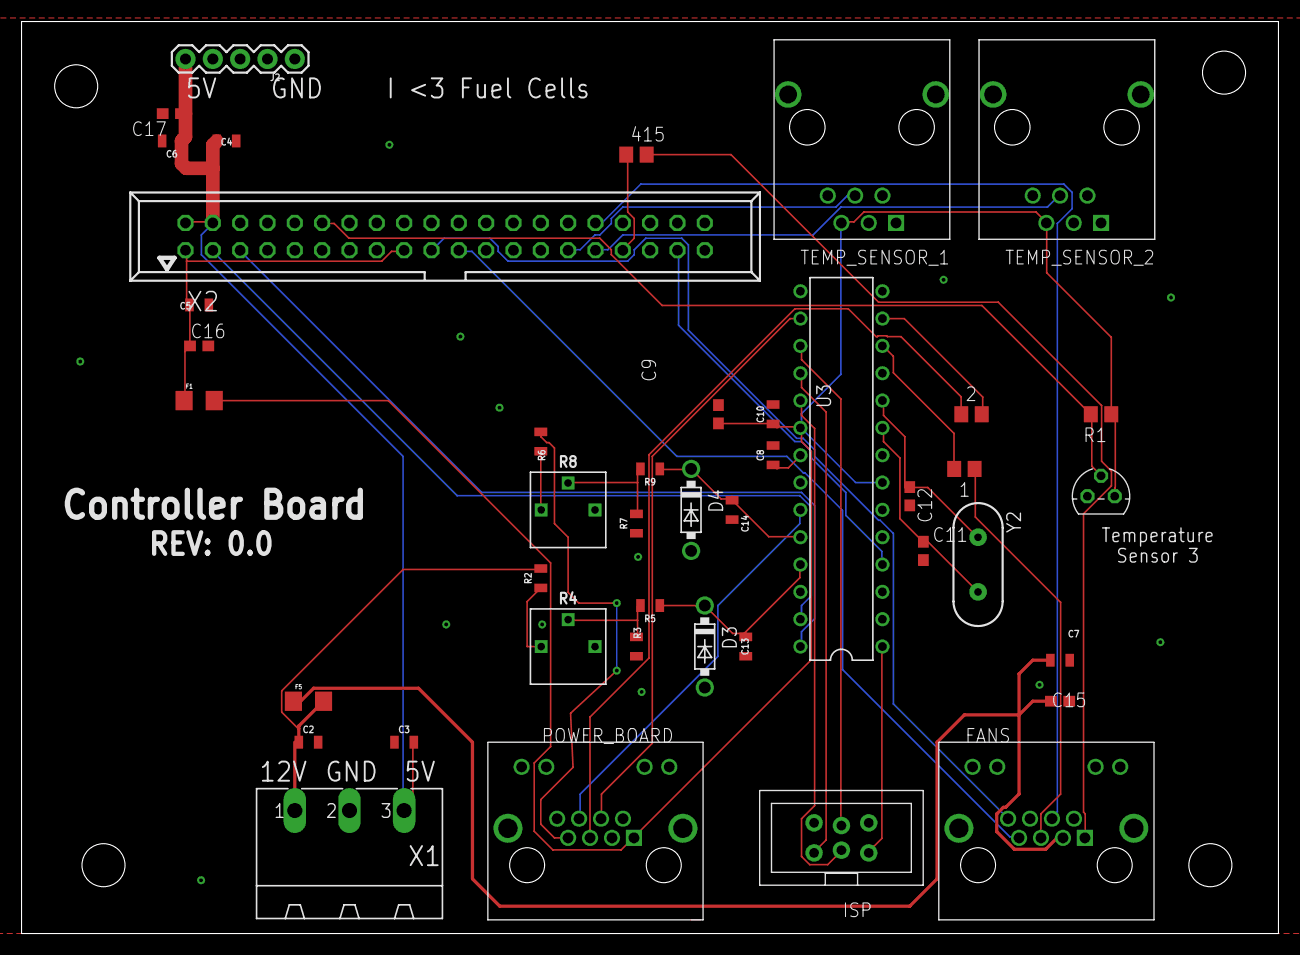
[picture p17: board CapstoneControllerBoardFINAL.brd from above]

Board: 2 copper layers, 116.8 x 84.8 mm, 44 parts (0 on the bottom side), 37 nets.

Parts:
1, 2: 110; R0805
415: R0805
C2, C3, C4, C5, C6, C7, C8, C10, C13, C14: 0.1uF; 0805
C9, C15, C16, C17: 10uF; C0603
C11, C12: 22pF; C0603
D3, D4: 3.3V Zener; DO41-7.6
F1, F5: 1206
FANS: ETHERNET; A122645-ND
FRAME2: FRAME-LETTERNO_PACKAGE; DUMMY
ISP: AVRISP-BOX
J2: 1X05
POWER_BOARD: ETHERNET; A122645-ND
R1: R0805
R2: 2.4k; 0805
R3: 1.2k; 0805
R4, R8: 0-5k; TRIM_POT
R5, R9: 5k; 0805
R6: 16k; 0805
R7: 1.3k; 0805
TEMP_SENSOR_1, TEMP_SENSOR_2: 5555140-6; 1734723-1_RJ11
U3: ATmega328P PDIP; PDIP-T28
U$2: DS18B; TO92
X1: MSTBA3
X2: 057-040-1
Y2: HC49US

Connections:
3.3V: C9.1, C10.1, F1.2, POWER_BOARD.P$1, R1.1, TEMP_SENSOR_1.5, TEMP_SENSOR_2.5, U3.7, U3.20, U$2.3
12V: C2.1, F5.2, R2.2, X1.1
46V: POWER_BOARD.P$7, R6.2
+5V: C3.2, C4.1, C6.1, C17.1, J2.5, X1.3, X2.2, X2.4
AIR_STARVE_RELAY: 2.1, POWER_BOARD.P$5
DQ_1: TEMP_SENSOR_1.4, X2.29
DQ_2: TEMP_SENSOR_2.4, X2.31
DQ_3: R1.2, U$2.2, X2.12
EXTRA_PIN_1: FANS.P$8, X2.19
EXTRA_PIN_2: FANS.P$7, X2.21
FAN_PWM: 415.2, FANS.P$1
FAN_PWM_ATMEL: 1.1, FANS.P$5
FUEL_CELL_CURRENT1: POWER_BOARD.P$6, U3.23
GATE_SIG: POWER_BOARD.P$4, U3.16
GND: C2.2, C3.1, C4.2, C5.2, C6.2, C7.2, C8.2, C9.2, C10.2, C11.2, C12.2, C13.2, C14.2, C15.2, C16.2, C17.2, D3.A, D4.A, FANS.P$2, FANS.P$6, FANS.P$13, FANS.P$14, ISP.6, J2.1, POWER_BOARD.P$2, POWER_BOARD.P$3, POWER_BOARD.P$8, POWER_BOARD.P$13, POWER_BOARD.P$14, R3.1, R7.1, TEMP_SENSOR_1.3, TEMP_SENSOR_1.SH1, TEMP_SENSOR_1.SH2, TEMP_SENSOR_2.3, TEMP_SENSOR_2.SH1, TEMP_SENSOR_2.SH2, U3.8, U3.22, U$2.1, X1.2, X2.9, X2.14, X2.20, X2.25, X2.30, X2.39
LOAD_ENABLE: U3.4, X2.37
unnamed: C8.1, U3.21
unnamed: ISP.1, U3.18
unnamed: ISP.3, U3.19
unnamed: 415.1, X2.33
unnamed: R2.1, R4.1
unnamed: 1.2, U3.12
unnamed: C5.1, C16.1, F1.1, X2.1, X2.17
unnamed: R6.1, R8.1
unnamed: R3.2, R4.2, R5.2
unnamed: ISP.4, U3.17
unnamed: C11.1, U3.9, Y2.2
unnamed: C12.1, U3.10, Y2.1
unnamed: R7.2, R8.2, R9.2
unnamed: C7.1, C15.1, F5.1, FANS.P$3
unnamed: 2.2, U3.13
RESET: ISP.5, U3.1
SCALED_BATT_V: C13.1, D3.C, R5.1, U3.25
SCALED_FUEL_CELL_V: C14.1, D4.C, R9.1, U3.24
SCL: U3.28, X2.5
SDA: U3.27, X2.3
WARNING_LED: FANS.P$4, X2.32

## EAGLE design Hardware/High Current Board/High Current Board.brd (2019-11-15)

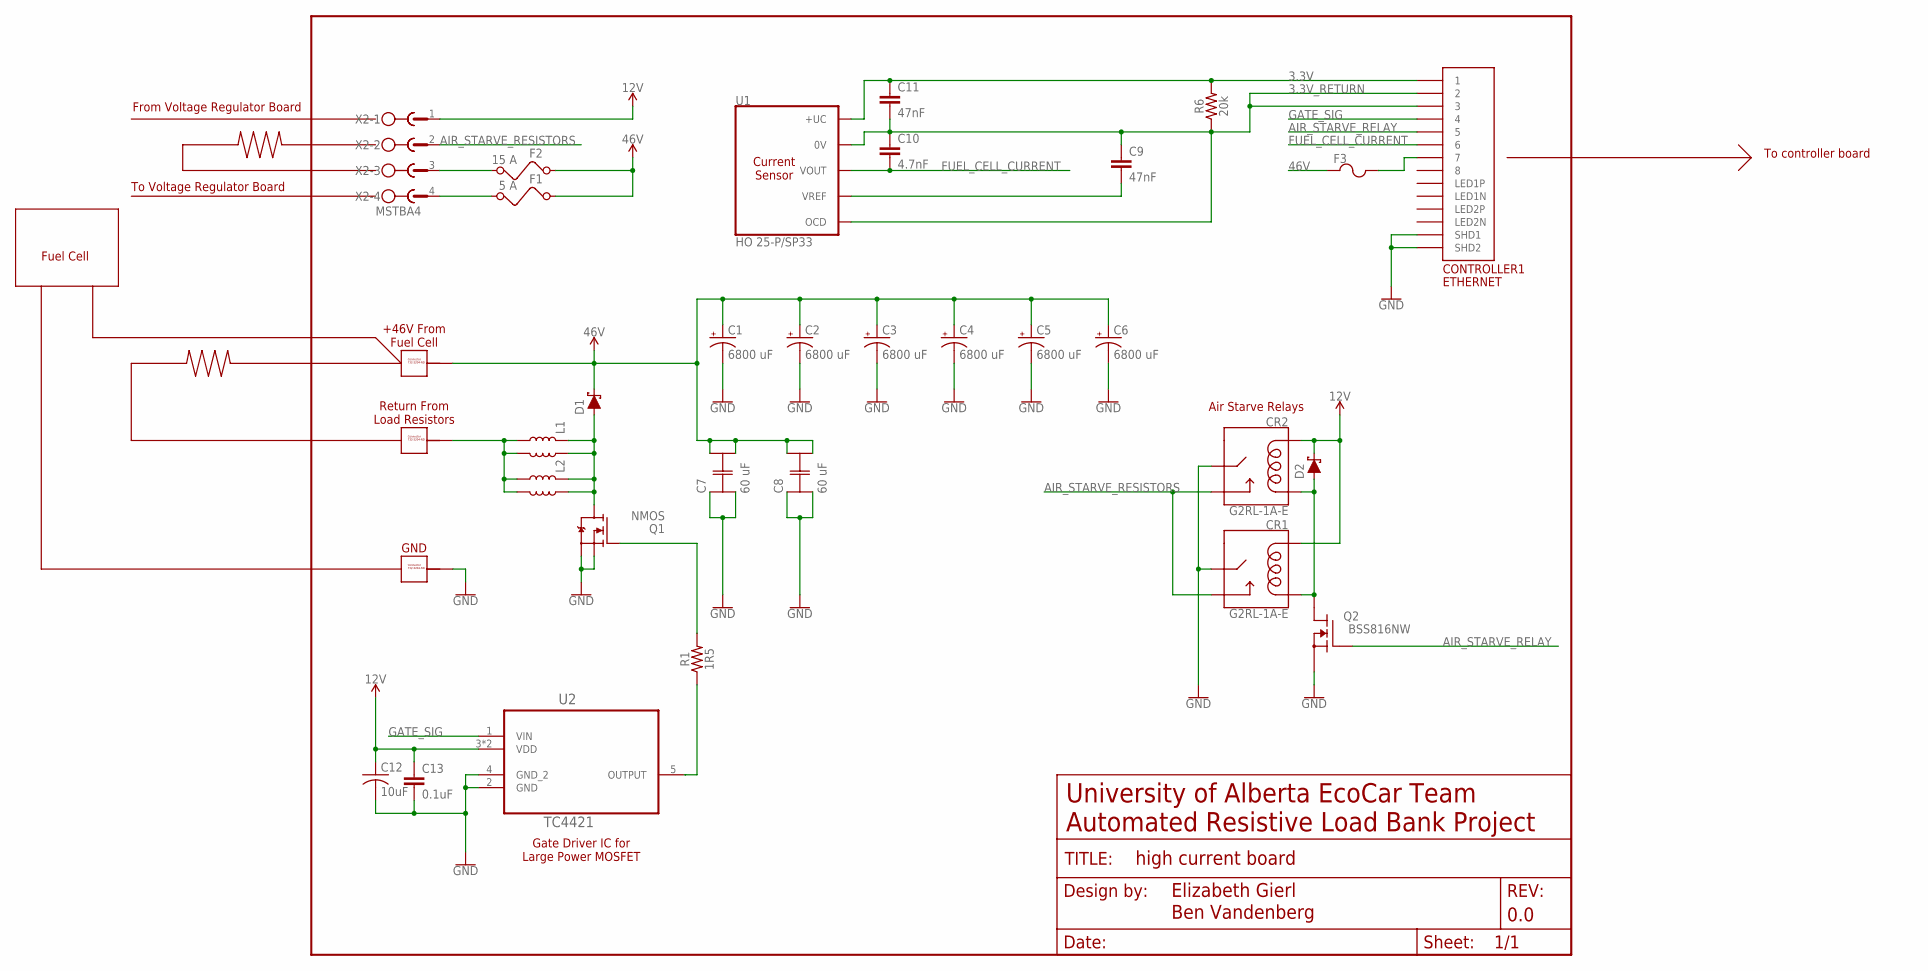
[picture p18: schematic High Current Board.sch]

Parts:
C1, C2, C3, C4, C5, C6: 6800 uF; CPOL-RADIAL-10MM-35MM
C7, C8: 60 uF; C4A-0(60)
C9, C11: 47nF; 0805
C10: 4.7nF; 0805
C12: 10uF; C0603
C13: 0.1uF; 0805
CONTROLLER1: ETHERNET; A122645-ND
CR1, CR2: G2RL-1A-E; G2RL-1A-E_RELAY
D1: D-67_HALF-PAK
D2: SOD-123F
F1: 5 A; KEYSTONE_ATM_FUSEHOLDER
F2: 15 A; KEYSTONE_ATM_FUSEHOLDER
F3: POLYFUSE; 1206
FC.GND1, FC.GND2, FC.POS: 732-3204-ND_CONNECTOR; 732-3204-ND
FRAME1: FRAME-LETTERNO_PACKAGE; DUMMY
L1, L2: CMX1616Z171B-10
Q1: NMOS; SOT-227
Q2: BSS816NW; SOT-323
R1: 1R5; SMD_2512
R6: 20k; 0805
U1: HO 25-P/SP33; LEM_HO_25-P
U2: TC4421; TO220-52
X2: MSTBA4

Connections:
3.3V: C11.1, CONTROLLER1.P$1 (1), R6.2, U1.1 (+UC)
3.3V_RETURN: C9.1, C10.1, C11.2, CONTROLLER1.P$2 (2), CONTROLLER1.P$3 (3), R6.1, U1.2 (0V), U1.5 (OCD)
12V: C12.1, C13.1, CR1.1 (COIL1), CR2.1 (COIL1), D2.C, U2.3 (VDD), U2.P$1 (VDD), X2.1
46V: C1.+, C2.+, C3.+, C4.+, C5.+, C6.+, C7.3, C7.4, C8.3, C8.4, D1.C, F1.L1 (1), F1.L2 (1), F2.L1 (1), F2.L2 (1), F3.1, FC.POS.P$1, FC.POS.P$2, FC.POS.P$3, FC.POS.P$4, FC.POS.P$5, FC.POS.P$6, FC.POS.P$7, FC.POS.P$8, FC.POS.P$9, FC.POS.P$10
AIR_STARVE_RELAY: CONTROLLER1.P$5 (5), Q2.1G (G)
AIR_STARVE_RESISTORS: CR1.4 (NO), CR1.5 (NO), CR2.4 (NO), CR2.5 (NO), X2.2
FUEL_CELL_CURRENT: C10.2, CONTROLLER1.P$6 (6), U1.3 (VOUT)
GATE_DRIVE: Q1.G, Q1.G2 (G), R1.P$2 (2)
GATE_SIG: CONTROLLER1.P$4 (4), U2.1 (VIN)
GND: C1.-, C2.-, C3.-, C4.-, C5.-, C6.-, C7.1, C7.2, C8.1, C8.2, C12.2, C13.2, CONTROLLER1.P$13 (SHD1), CONTROLLER1.P$14 (SHD2), CR1.3 (MAIN), CR1.6 (MAIN), CR2.3 (MAIN), CR2.6 (MAIN), FC.GND2.P$1, FC.GND2.P$2, FC.GND2.P$3, FC.GND2.P$4, FC.GND2.P$5, FC.GND2.P$6, FC.GND2.P$7, FC.GND2.P$8, FC.GND2.P$9, FC.GND2.P$10, Q1.S1 (S), Q1.S2 (S1), Q1.S3 (S), Q1.S4 (S1), Q2.2S (S), U2.2 (GND), U2.4 (GND_2)
unnamed: C9.2, U1.4 (VREF)
unnamed: FC.GND1.P$1, FC.GND1.P$2, FC.GND1.P$3, FC.GND1.P$4, FC.GND1.P$5, FC.GND1.P$6, FC.GND1.P$7, FC.GND1.P$8, FC.GND1.P$9, FC.GND1.P$10, L1.R1 (B1), L1.R2 (B2), L1.R11 (B1), L1.R22 (B2), L2.R1 (B1), L2.R2 (B2), L2.R11 (B1), L2.R22 (B2)
unnamed: CR1.8 (COIL2), CR2.8 (COIL2), D2.A, Q2.3D (D)
unnamed: L1.L1 (T1), L1.L2 (T2), L1.L11 (T1), L1.L22 (T2), L2.L1 (T1), L2.L2 (T2), L2.L11 (T1), L2.L22 (T2), Q1.D, Q1.D2 (D)
unnamed: F2.R1 (2), F2.R2 (2), X2.3
unnamed: F1.R1 (2), F1.R2 (2), X2.4
unnamed: R1.P$1 (1), U2.5 (OUTPUT)
unnamed: CONTROLLER1.P$7 (7), F3.2

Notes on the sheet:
University of Alberta EcoCar Team Automated Resistive Load Bank Project
Elizabeth Gierl
Current Sensor
+46V From Fuel Cell
Return From Load Resistors
GND
Air Starve Relays
Gate Driver IC for Large Power MOSFET
Fuel Cell
To controller board
To Voltage Regulator Board
From Voltage Regulator Board

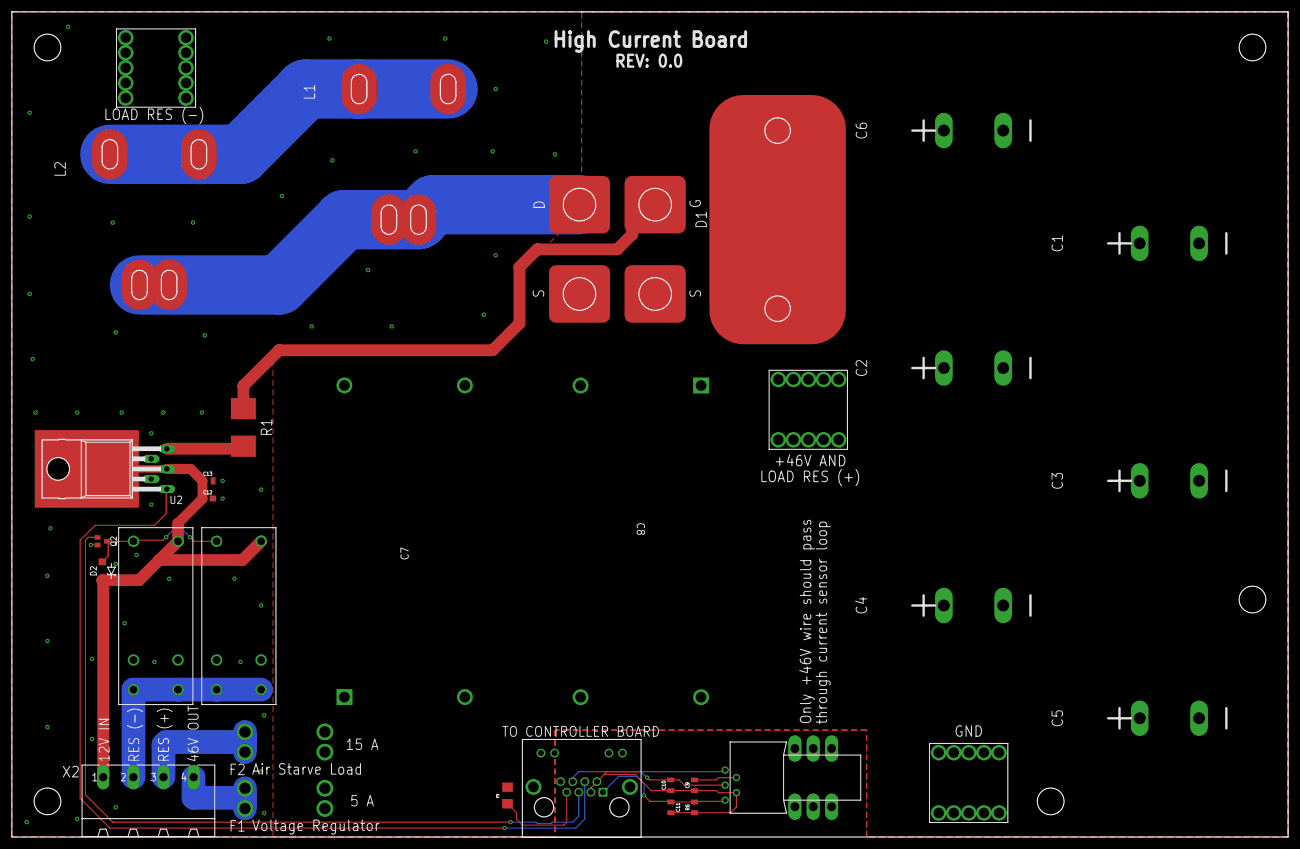
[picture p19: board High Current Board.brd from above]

Board: 2 copper layers, 215.0 x 139.0 mm, 34 parts (0 on the bottom side), 18 nets.

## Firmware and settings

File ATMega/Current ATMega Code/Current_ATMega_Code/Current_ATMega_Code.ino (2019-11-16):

 /*                                                                            Load Bank Atmel Code
                                                                               EcoCar FC Team 
                                                                               Elizabeth Gierl
                                                                               Spring Summer 2019                                                                          */

#include <Wire.h>
#define SLAVE_ADDRESS 0x08
#include <PID_v1.h>
#include <avr/wdt.h>

// PID CODES   
//Specify the links and initial tuning parameters 
double Setpoint, Input, Output;
PID loadPID(&Input, &Output, &Setpoint, 2, 5, 1, DIRECT);

// PID needs doubles is this a problem?
double Setpoint1, Input1, Output1;
PID fansPID(&Input1, &Output1, &Setpoint1, 2, 5, 1, DIRECT);

//GLOBAL VARIABLES
  char c[]={0,223,8,221};
  char  Atmega_Status=20; 
  char Pi_Status= 23;
  int FC_Volt=46; 
  int Battery_Volt=30; 
  char Desired_Temperature=1;
  char Load_Temperature= 1;
  char Control_Temperature=2;
  int CurrentCurrent=40;
  char DesiredCurrent=3; 
  char CellVoltageLow=5;
  char CellVoltageHigh=5;
  char BatteryVoltageLow=5;
  char BatteryVoltageHigh=5;
  char CellCurrentLow=5;
  char CellCurrentHigh=5;
  char AirStarve_Set=0;
  char Current_Temperature=80;


void setup() { 
 //I2C Setup
 Wire.begin(SLAVE_ADDRESS);        // join i2c bus with address #8
 Wire.onRequest(Write_to_Pi); // register event
 Wire.onReceive(Read_From_Pi); // register event
 //Serial setup
 Serial.begin(9600);  
  //turn the PID on
 fansPID.SetMode(AUTOMATIC);
// loadPID.SetMode(AUTOMATIC);
 pinMode(13, OUTPUT); //for airstarve relay
 //watchdog setup
 watchdogSetup();
// analogReference(EXTERNAL); //CONNECT 3.3 line from atmel chip to AREF MAY NEED TO DO THIS! 
Serial.print(3);
}



//MAIN LOOP
void loop() { 
  Serial.print(5);
 //Call functions
 attachInterrupt(digitalPinToInterrupt(2), saftey_pin, FALLING);
 PWM25kHzBegin();
 initAnalog();
 Read_From_Atmega(); 
 AirStarve();

// over current saftey check
 if (CurrentCurrent > 60){
      DesiredCurrent=0;
      AirStarve_Set=0;
      Desired_Temperature=40;
      Atmega_Status=6;
      //what number is max desired fan speed 
 }

Pi_Status=0;
switch (Pi_Status) {
    case 0:
      Serial.println("Booting Up"); 
      Atmega_Status=0;
      break;
    case 1:
      Serial.println("Establishing I2C"); 
      break;
    case 2:
      Serial.println("Communication Established"); 
      Atmega_Status=2; 
      break;
    case 3:
      Serial.println("Normal Operation"); 
      break;
    case 4:
      Serial.println("Over Temperature in load region"); 
      DesiredCurrent=0;
      AirStarve_Set=0;
      Desired_Temperature=40;
      break;
    case 5:
      Serial.println("Over Temperature in control region"); 
      DesiredCurrent=0;
      AirStarve_Set=0;
      Desired_Temperature=40;
      break;
    case 6:
      Serial.println("Over Current"); 
      DesiredCurrent=0;
      AirStarve_Set=0;
      Desired_Temperature=40;
      break;
    case 7:
      Serial.println("Cell voltage is too high"); 
      DesiredCurrent=0;
      AirStarve_Set=0;
      Desired_Temperature=40;
      break;
    case 8:
      Serial.println("Cell voltage is too low"); 
      DesiredCurrent=0;
      AirStarve_Set=0;
      Desired_Temperature=40;
      break;
    case 9:
      Serial.println("Battery Voltage is too Low"); 
      DesiredCurrent=0;
      AirStarve_Set=0;
      Desired_Temperature=40;
      break;
    case 10:
      AirStarve_Set=1;
      break;
    default: 
      Serial.println("Lost Communication"); 
    break;
  }
  
Load_Temperature=140;
Control_Temperature=10;

//Fans:
//if the temperature is 50 degrees, a value of 100 is sent from the pi 
//max temperature is 85 degrees 
if (Load_Temperature > 140){
  Current_Temperature=Load_Temperature;
}
else if (Control_Temperature >140){
  Current_Temperature=Control_Temperature ;
}
else{
  Current_Temperature= ((Control_Temperature+Load_Temperature)/2);
}

Serial.print(1);
Serial.print(Output1);
Setpoint1= Desired_Temperature;
Input1= Current_Temperature;
fansPID.Compute();
Serial.print(Output1);
analogWrite(12,Output1);

//The PID controller is designed to vary its output within a given range. By default this range is 0-255:

 Load Control
loadPID.SetOutputLimits(0, 640);
Setpoint= DesiredCurrent; 
Input= CurrentCurrent;
loadPID.Compute();
OCR1B=Output; 

}


//:^)




//FUNCTIONS:

void PWM25kHzBegin() {
  //Conditioning:
  TCCR1A = 0;
  TCCR1B = 0;
  OCR1A = 640; 
  OCR1B = 0;
  DDRB |= (1<<PINB2);
  TCCR1A |= (1<<COM1A1)|(1<<COM1B1)|(1<<WGM11)|(1<<WGM10);    //Non-inverting Mode - Clear OC1A/OC1B on Compare Match, Set at BOTTOM
  TCCR1B |= (1<<CS10)|(1<<WGM13)|(1<<WGM12); //prescalar 1    // 25kHz
}

void initAnalog(){
  ADMUX = (ADMUX | (1<<REFS0)) & ~(1<<REFS1);                 // Set analog reference to external A_ref
  ADCSRA |= (1<<ADEN) | (1<<ADPS2) | (1<<ADPS1) | (1<<ADPS0); // Enable analog to digital conversion. Set div/8 pre-scaler for ADC clock.
  DIDR0 |= (1<<ADC3D);                                        // Disable digital output on ADC3
  PRR &= ~(1<<PRADC);                                         // Turn off power reduction
  ADMUX &= 0xF0;                                              // Set ADC input to given parameter by clearing input selection bits, then setting to ADC3
  ADMUX |= 3;
}

void watchdogSetup(void)
{
  // set it so reset is enabled after two seconds without any interrupts
  cli(); // disable all interrupts
  wdt_reset(); // reset the WDT timer
  /*
   WDTCSR configuration:
   WDIE = 1: Interrupt Enable
   WDE = 1 :Reset Enable
   WDP3 = 0 :For 2000ms Time-out
   WDP2 = 1 :For 2000ms Time-out
   WDP1 = 1 :For 2000ms Time-out
   WDP0 = 1 :For 2000ms Time-out
  */
  
  // Enter Watchdog Configuration mode:
  WDTCSR |= (1<<WDCE) | (1<<WDE);
  // Set Watchdog settings:
   WDTCSR = (1<<WDE) | (0<<WDP3) | (1<<WDP2) | (1<<WDP1) | (1<<WDP0);
  sei();
}

void saftey_pin()  //interupt saftey pin        
{                   
   DesiredCurrent=0;
   AirStarve_Set=0;
   Desired_Temperature=40;                            
   Serial.println("Saftey Button Interrupt");
}

void  Read_From_Atmega() {
  char  Atmega_Status=2;//how should we collect this?
  int FC_Volt=analogRead(A1);
  int Battery_Volt=analogRead(A2);
  int CurrentCurrent=analogRead(A0);
  //char Fan_Speed=????
  CurrentCurrent=(31.25)*(CurrentCurrent)+140.63;
  //^this could be further varified for higher accuracy

  //if over current
 if (CurrentCurrent > 60){
      DesiredCurrent=0;
      AirStarve_Set=0;
      Desired_Temperature=20;
      Atmega_Status=6;
      //what number is max desired fan speed 
 }
 
  char CellVoltageLow=lowByte(FC_Volt);
  char CellVoltageHigh=highByte(FC_Volt);
  char BatteryVoltageLow=lowByte(Battery_Volt);
  char BatteryVoltageHigh=highByte(Battery_Volt);
  char CellCurrentLow= lowByte(CurrentCurrent);
  char CellCurrentHigh= highByte(CurrentCurrent);
}

void Read_From_Pi(int howMany) {
  int i=0;
while ( Wire.available()) { // loop through all but the last
    c[i] = Wire.read(); // receive byte as a character
    Serial.print(c[i]);
    i++;      
    }
  Pi_Status=c[1];
  Desired_Temperature=c[2];
  Load_Temperature=c[3];
  Control_Temperature=c[4];
  DesiredCurrent=c[5];
  wdt_reset();

}
  
void Write_to_Pi() {  
//c[0] always gives a bad value and cannot be used
 char badvalue=5;
 char data[] ={badvalue,Atmega_Status,CellCurrentHigh, CellCurrentLow, CellVoltageHigh,CellVoltageLow,BatteryVoltageHigh,BatteryVoltageLow};
 Wire.write(data); 
}


void AirStarve(){
  if(AirStarve_Set==1){
    digitalWrite(13, HIGH);
  }
  else{
    digitalWrite(13, LOW);
  }
}

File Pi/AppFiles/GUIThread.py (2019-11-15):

import threading
import tkinter as tk
from AppFiles import I2CThread
import time
from AppFiles import model

class GUIThread (threading.Thread):
    def __init__(self, threadID, name, counter):
        threading.Thread.__init__(self)
        self.threadID = threadID
        self.name = name
        self.counter = counter
    def run(self):
        print("Starting " + self.name)
        # Create the main window
        root = tk.Tk()
        root.title("EcoCar GUI")         
        # Set window size to match 7" SparkFun LCD (800 x 480)
        root.resizable(False, False)
        root.geometry("800x480")

        #Data for live update of GUI
        PiData0 = tk.IntVar()
        PiData1 = tk.IntVar()
        PiData2 = tk.IntVar()

        #Display Variable Values for Pi and ATMega
        PiDataTitle = tk.Label(root, text="Pi Data")
        PiDataTitle.pack()

        PiDataLabel1 = tk.Label(root, textvariable=PiData0)
        PiDataLabel1.pack()
        PiDataLabel2 = tk.Label(root, textvariable=PiData1)
        PiDataLabel2.pack()
        PiDataLabel3 = tk.Label(root, textvariable=PiData2)
        PiDataLabel3.pack()
        #PiDataUpdateButton = tk.Button(root, text="Increment Values", command=)
        #PiDataUpdateButton.pack()
        
        # Temp line for debugging
        EcoCar = model.EcoCarModel()
        
        while 1:
            root.update()
            PiData0.set(I2CThread.PiData[0])
            PiData1.set(I2CThread.PiData[1])
            PiData2.set(I2CThread.PiData[2])
            time.sleep(1)
            
            # Temp line for debugging
            EcoCar.refreshI2CData()
        

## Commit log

2023-12-02 work on temp sensor board
2023-12-02 Changed Schematic for Temp Sens Board
    [Temperature Senor Board V2 (2)-B_Cu.gbl, Temperature Senor Board V2 (2)-B_Mask.gbs, Temperature Senor Board V2 (2)-B_Paste.gbp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]
2023-12-02 Gerber File Changed
    [Temperature Senor Board V2 (2)-B_Cu.gbl, Temperature Senor Board V2 (2)-B_Mask.gbs, Temperature Senor Board V2 (2)-B_Paste.gbp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]
2023-12-03 Added File for Temperature Sensor Board 1 and Temperature Sensor Board 2
    [Temp Sensor Board 1-B_Cu.gbr, Temp Sensor Board 1-B_Mask.gbr, Temp Sensor Board 1-B_Paste.gbr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]
2024-01-01 complete gerber for temp sensors
    [Temp Sensor Board 1-B_Cu.gbl, Temp Sensor Board 1-B_Cu.gbr, Temp Sensor Board 1-B_Mask.gbr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]

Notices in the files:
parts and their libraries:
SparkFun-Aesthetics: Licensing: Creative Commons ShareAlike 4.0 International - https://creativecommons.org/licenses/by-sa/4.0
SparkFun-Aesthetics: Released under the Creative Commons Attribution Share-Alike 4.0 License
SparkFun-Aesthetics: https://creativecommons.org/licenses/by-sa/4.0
